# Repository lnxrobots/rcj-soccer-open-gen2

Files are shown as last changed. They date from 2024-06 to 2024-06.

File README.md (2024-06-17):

# RoboCup Soccer Open, Gen 2

## Setup

### Clone

Clone this repository in the home directory.

### Enable SSH and UART

Using `sudo raspi-config`

### Install packages and libraries

```
sudo apt install python3-pip git i2c-tools python3-opencv python3-serial python3-websockets
```

```
pip3 install bluedot
```

### Set cameras and optionally disable builtin Bluetooth

Add following lines to `/boot/firmware/config.txt`, change cameras if needed:

```
# Automatically load overlays for detected cameras
camera_auto_detect=0
dtoverlay=imx708,rotation=0,cam0
dtoverlay=imx477,cam1

# Uncomment to disable builtin bluetooth - custom
#dtoverlay=disable-bt
```

### Add launcher to autostart

Run `Launcher/apply_service.sh`.

### Pairing robots

Pair using [bluedot manual](https://bluedot.readthedocs.io/en/latest/pairpipi.html).

### Camera

Obtain frames using [Picamera2](https://github.com/raspberrypi/picamera2).

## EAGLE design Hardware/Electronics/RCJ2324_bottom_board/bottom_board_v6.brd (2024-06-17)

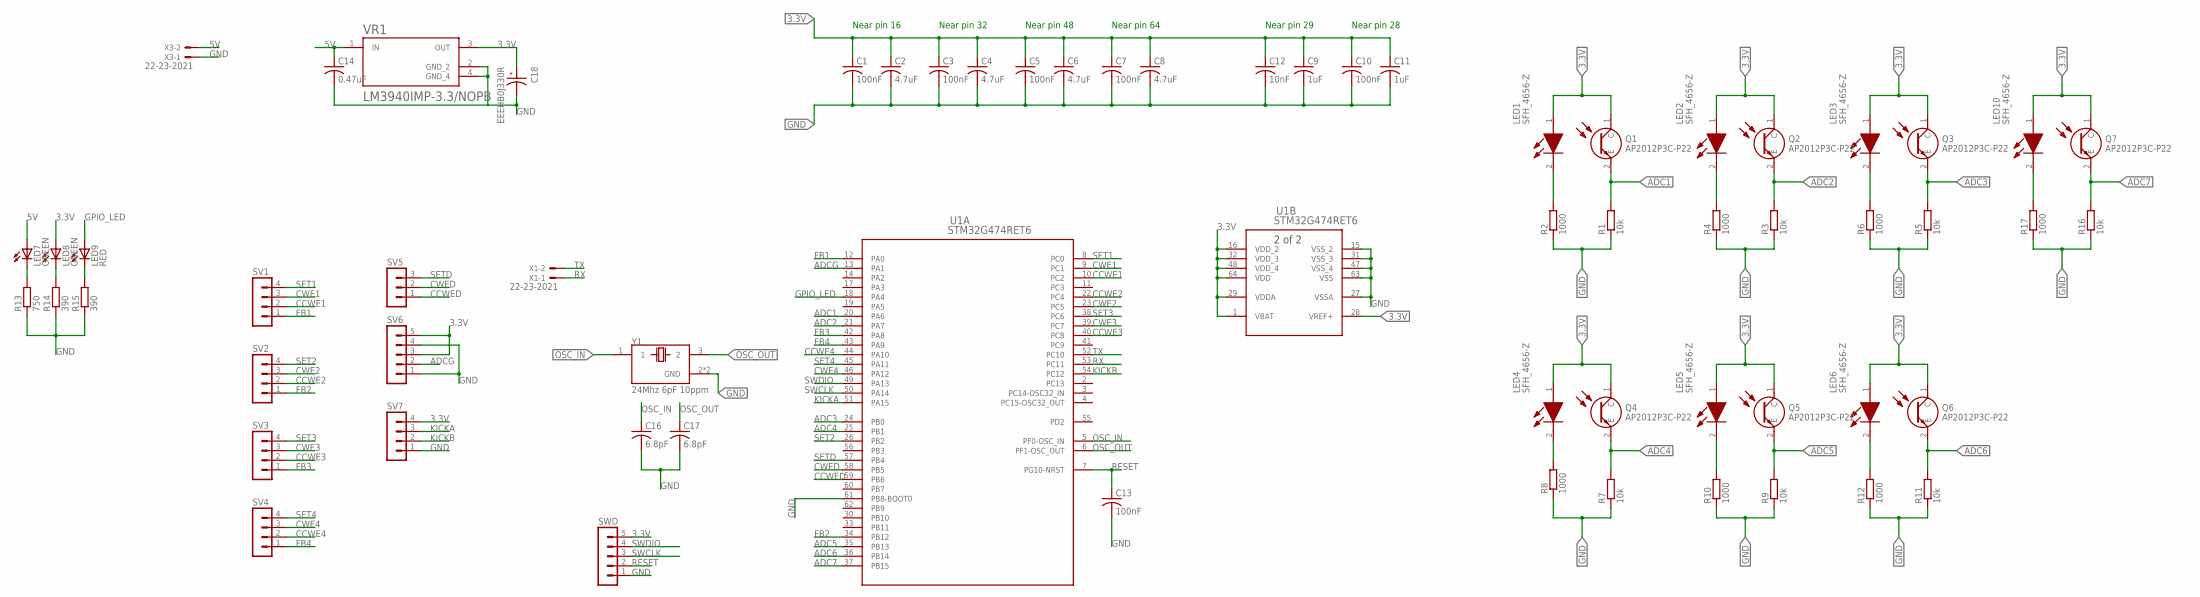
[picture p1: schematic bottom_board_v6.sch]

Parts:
C1, C3, C5, C7, C10, C13: 100nF; C0603
C2, C4, C6, C8: 4.7uF; C0603
C9, C11: 1uF; C0603
C12: 10nF; C0603
C14: 0.47uF; C0603
C16, C17: 6.8pF; C0603
C18: EEEHB0J330R; CAP_EEEHB0J330R
LED1, LED2, LED3, LED4, LED5, LED6, LED10: SFH_4656-Z; SFH4656Z
LED7, LED8: GREEN; CHIPLED_0603
LED9: RED; CHIPLED_0603
Q1, Q2, Q3, Q4, Q5, Q6, Q7: AP2012P3C-P22; AP2012P3CP22
R1, R3, R5, R7, R9, R11, R16: 10k; R0603
R2, R4, R6, R8, R10, R12, R17: 1000; R0603
R13: 750; R0603
R14, R15: 390; R0603
SV1, SV2, SV3, SV4, SV7: MA04-1
SV5: MA03-1
SV6: MA05-1
SWD: MA05-1
U1: STM32G474RET6; LQFP64-10X10MM
VR1: LM3940IMP-3.3/NOPB; VREG_LM3940IMP-3.3/NOPB
X1, X3: 22-23-2021
Y1: 24Mhz 6pF 10ppm; XTAL_TSX-3225_16.0000MF18X-AC3

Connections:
3.3V: C1.1, C2.1, C3.1, C4.1, C5.1, C6.1, C7.1, C8.1, C9.1, C10.1, C11.1, C12.1, C18.1, LED1.1 (A), LED2.1 (A), LED3.1 (A), LED4.1 (A), LED5.1 (A), LED6.1 (A), LED8.A, LED10.1 (A), Q1.1 (C), Q2.1 (C), Q3.1 (C), Q4.1 (C), Q5.1 (C), Q6.1 (C), Q7.1 (C), SV6.3, SV6.5, SV7.4, SWD.5, U1.1 (VBAT), U1.16 (VDD_2), U1.28 (VREF+), U1.29 (VDDA), U1.32 (VDD_3), U1.48 (VDD_4), U1.64 (VDD), VR1.3 (OUT)
5V: C14.1, LED7.A, VR1.1 (IN), X3.2
ADC1: Q1.2 (E), R1.2, U1.20 (PA6)
ADC2: Q2.2 (E), R3.2, U1.21 (PA7)
ADC3: Q3.2 (E), R5.2, U1.24 (PB0)
ADC4: Q4.2 (E), R7.2, U1.25 (PB1)
ADC5: Q5.2 (E), R9.2, U1.35 (PB13)
ADC6: Q6.2 (E), R11.2, U1.36 (PB14)
ADC7: Q7.2 (E), R16.2, U1.37 (PB15)
ADCG: SV6.2, U1.13 (PA1)
CCWE1: SV1.2, U1.10 (PC2)
CCWE2: SV2.2, U1.22 (PC4)
CCWE3: SV3.2, U1.40 (PC8)
CCWE4: SV4.2, U1.44 (PA10)
CCWED: SV5.1, U1.59 (PB6)
CWE1: SV1.3, U1.9 (PC1)
CWE2: SV2.3, U1.23 (PC5)
CWE3: SV3.3, U1.39 (PC7)
CWE4: SV4.3, U1.46 (PA12)
CWED: SV5.2, U1.58 (PB5)
FB1: SV1.1, U1.12 (PA0)
FB2: SV2.1, U1.34 (PB12)
FB3: SV3.1, U1.42 (PA8)
FB4: SV4.1, U1.43 (PA9)
GND: C1.2, C2.2, C3.2, C4.2, C5.2, C6.2, C7.2, C8.2, C9.2, C10.2, C11.2, C12.2, C13.2, C14.2, C16.2, C17.2, C18.2, R1.1, R2.1, R3.1, R4.1, R5.1, R6.1, R7.1, R8.1, R9.1, R10.1, R11.1, R12.1, R13.1, R14.1, R15.1, R16.1, R17.1, SV6.1, SV6.4, SV7.1, SWD.1, U1.15 (VSS_2), U1.27 (VSSA), U1.31 (VSS_3), U1.47 (VSS_4), U1.61 (PB8-BOOT0), U1.63 (VSS), VR1.2 (GND_2), VR1.4 (GND_4), X3.1, Y1.2 (GND), Y1.4 (GND)
GPIO_LED: LED9.A, U1.18 (PA4)
KICKA: SV7.3, U1.51 (PA15)
KICKB: SV7.2, U1.54 (PC12)
unnamed: LED2.2 (K), R4.2
unnamed: LED3.2 (K), R6.2
unnamed: LED1.2 (K), R2.2
unnamed: LED4.2 (K), R8.2
unnamed: LED5.2 (K), R10.2
unnamed: LED6.2 (K), R12.2
unnamed: LED7.C, R13.2
unnamed: LED8.C, R14.2
unnamed: LED9.C, R15.2
unnamed: LED10.2 (K), R17.2
OSC_IN: C16.1, U1.5 (PF0-OSC_IN), Y1.1
OSC_OUT: C17.1, U1.6 (PF1-OSC_OUT), Y1.3 (2)
RESET: C13.1, SWD.2, U1.7 (PG10-NRST)
RX: U1.53 (PC11), X1.1
SET1: SV1.4, U1.8 (PC0)
SET2: SV2.4, U1.26 (PB2)
SET3: SV3.4, U1.38 (PC6)
SET4: SV4.4, U1.45 (PA11)
SETD: SV5.3, U1.57 (PB4)
SWCLK: SWD.3, U1.50 (PA14)
SWDIO: SWD.4, U1.49 (PA13)
TX: U1.52 (PC10), X1.2

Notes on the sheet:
Near pin 16
Near pin 32
Near pin 48
Near pin 64
Near pin 29
Near pin 28

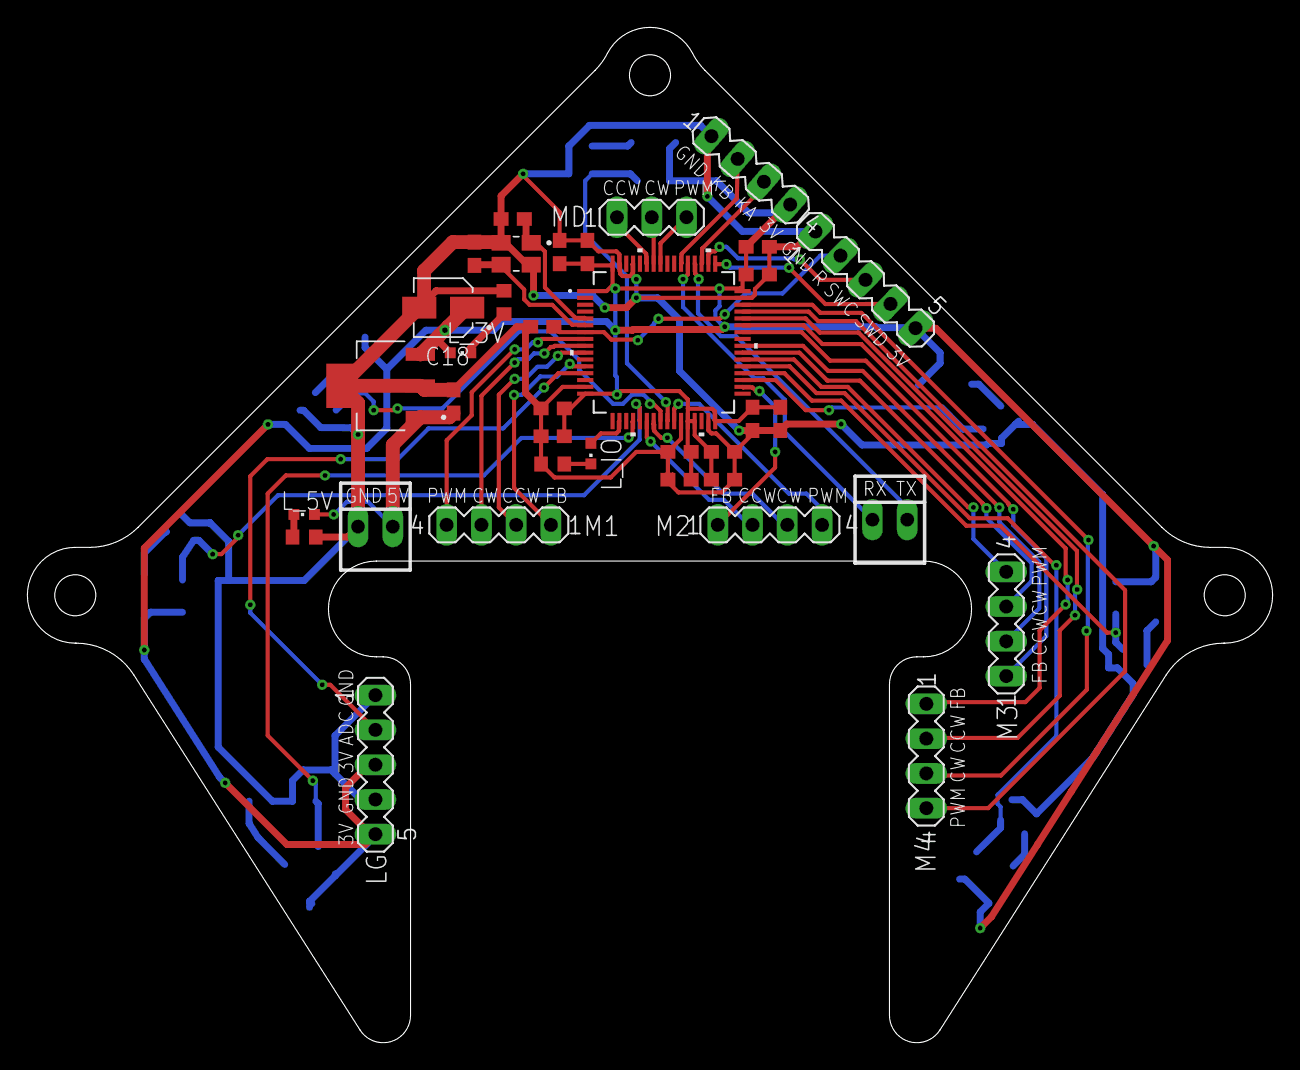
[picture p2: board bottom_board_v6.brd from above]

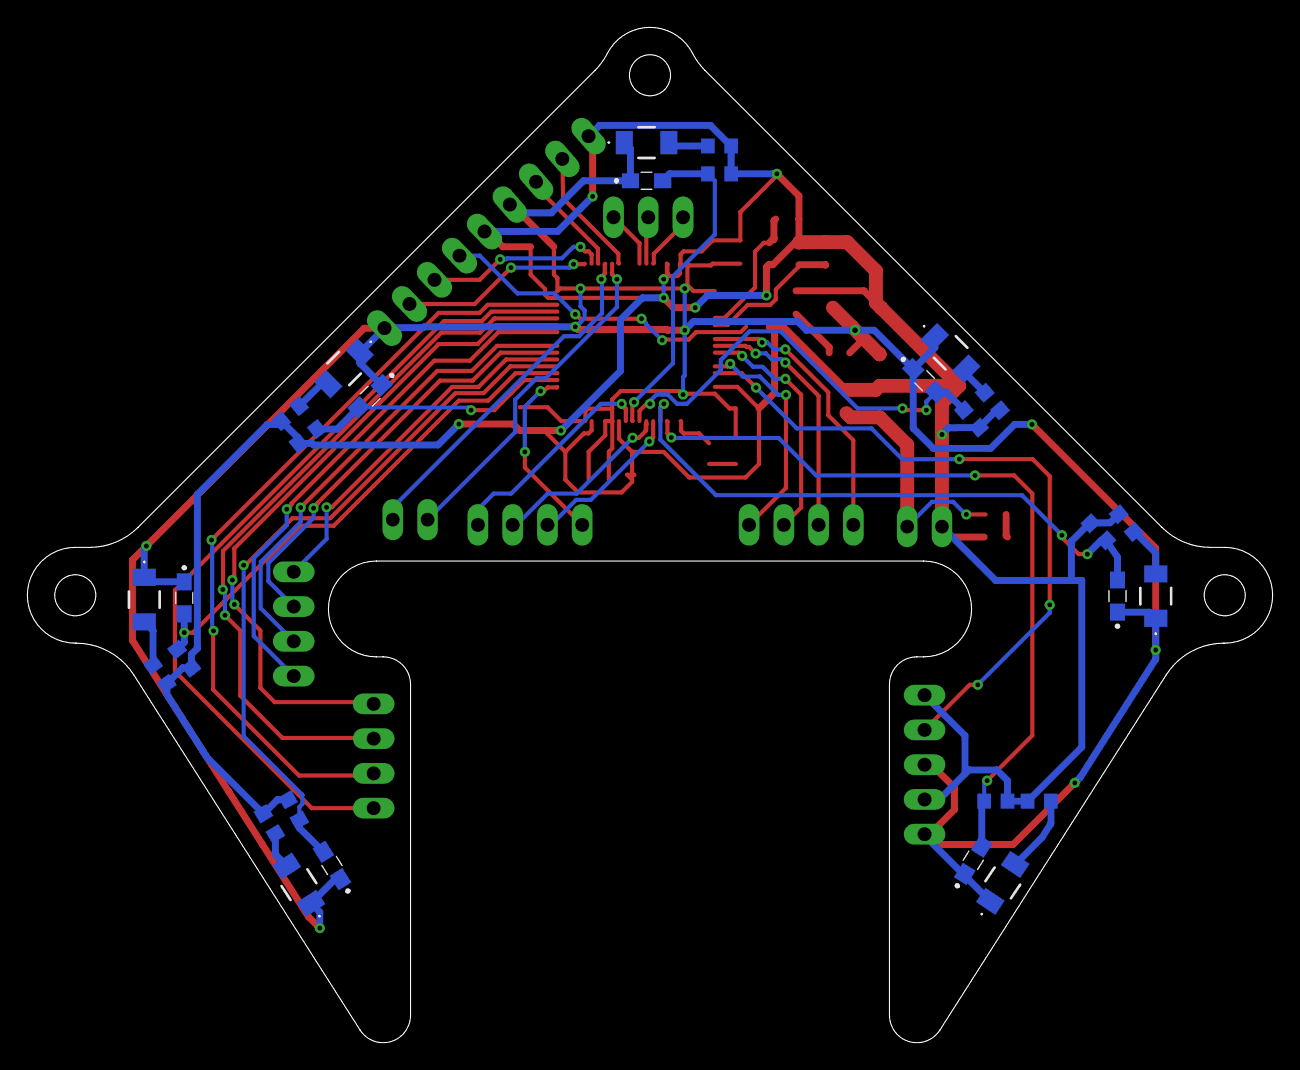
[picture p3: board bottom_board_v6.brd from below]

Board: 2 copper layers, 91.0 x 74.2 mm, 64 parts (28 on the bottom side), 50 nets.

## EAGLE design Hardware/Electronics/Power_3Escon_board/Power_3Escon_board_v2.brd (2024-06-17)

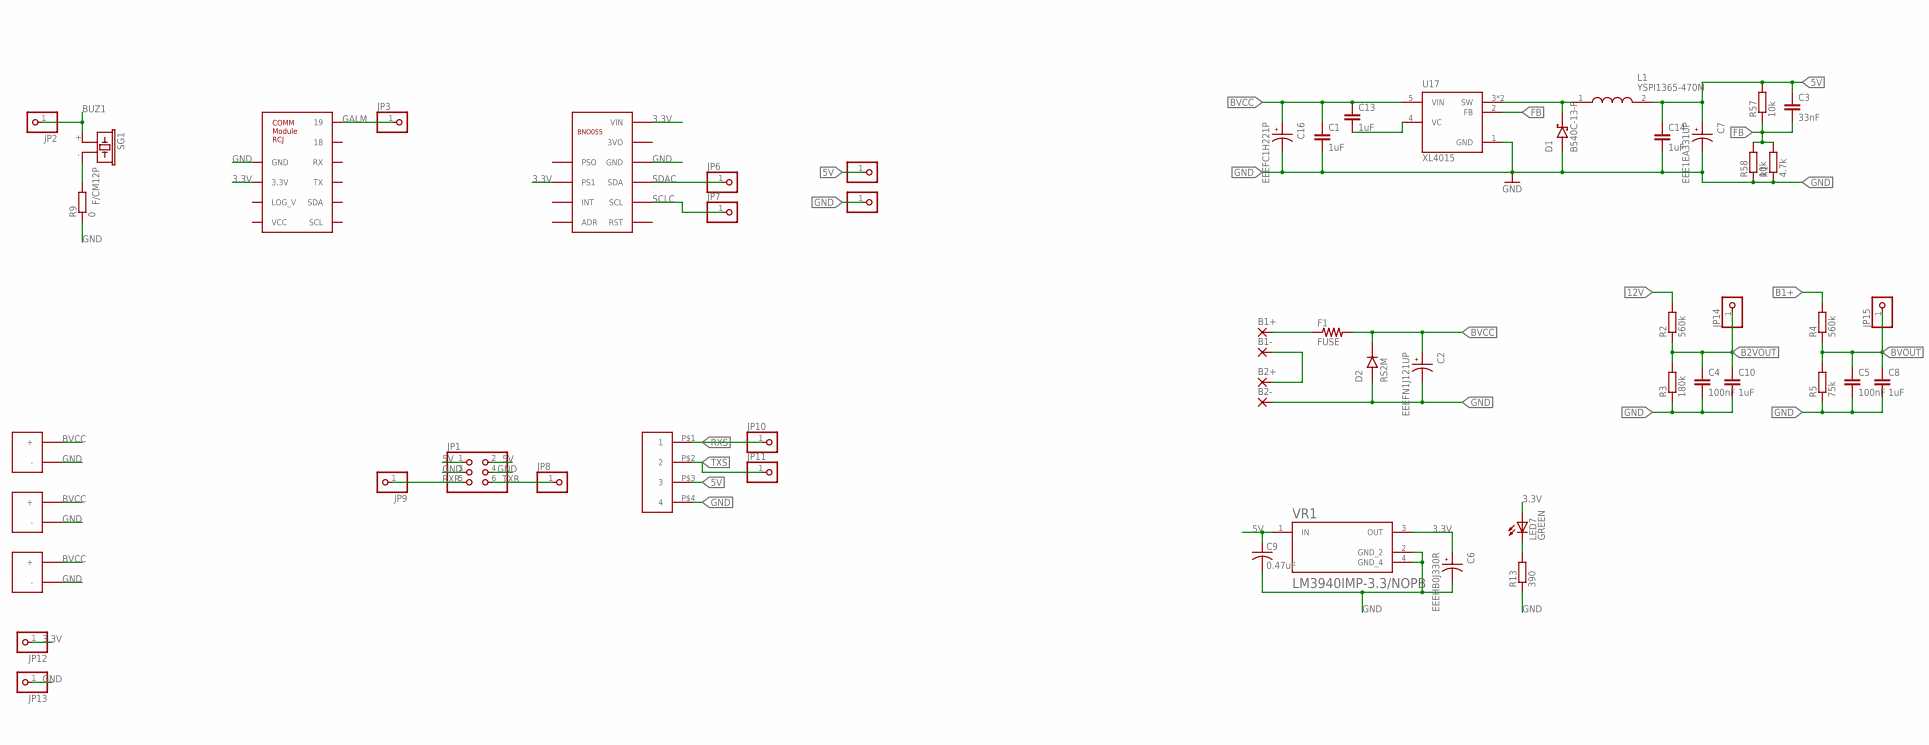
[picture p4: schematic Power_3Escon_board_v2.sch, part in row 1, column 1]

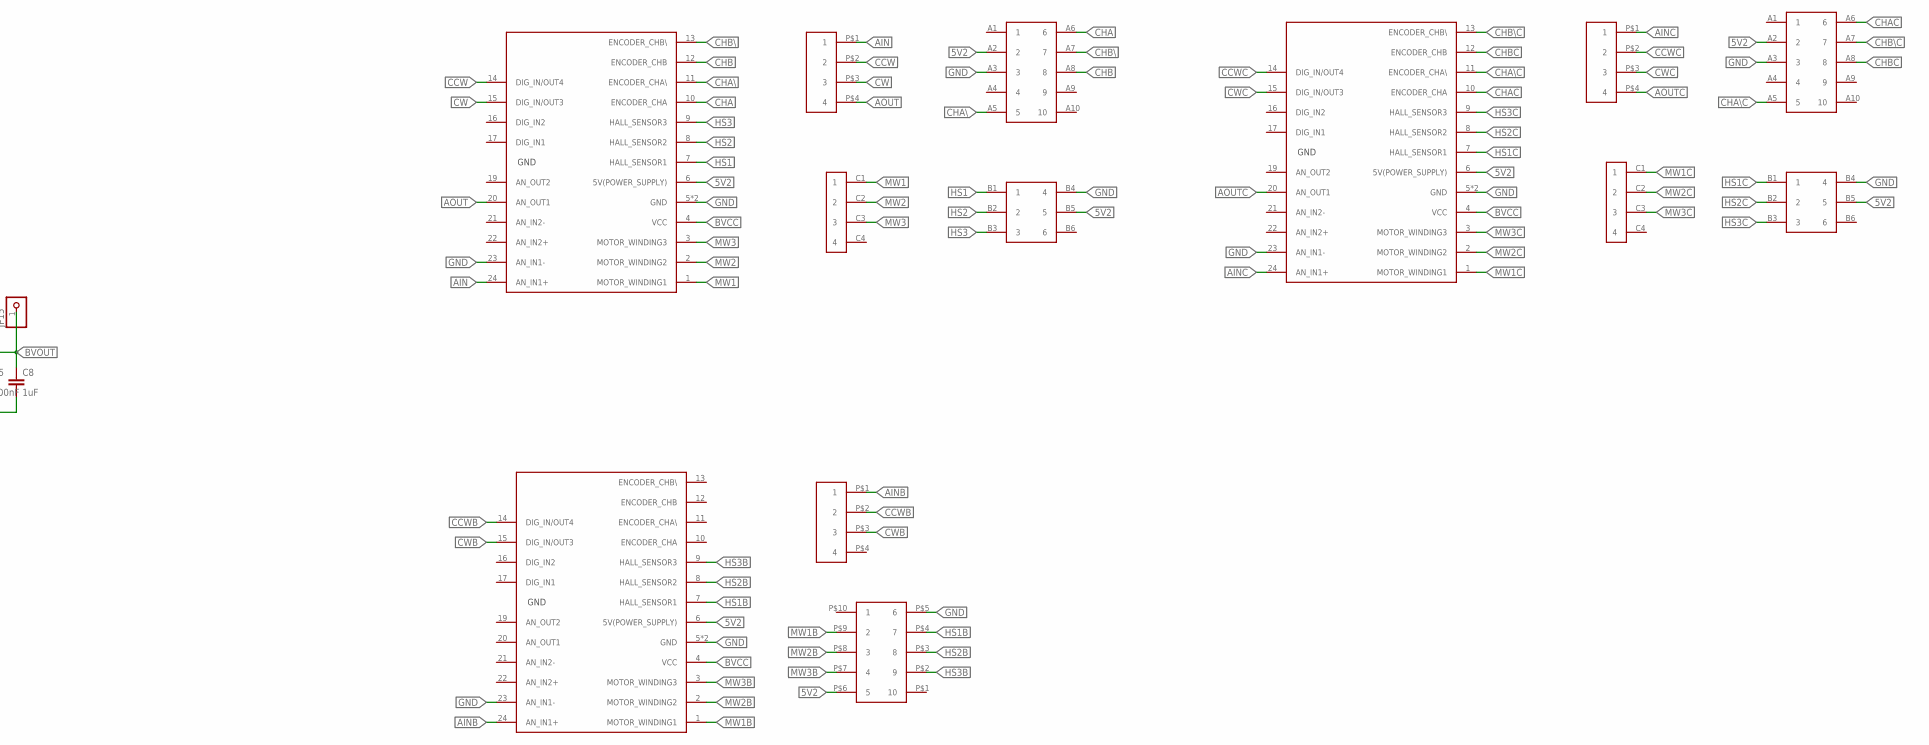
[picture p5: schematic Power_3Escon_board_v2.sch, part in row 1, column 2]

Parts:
B1+, B1-, B2+, B2-: 3,81/1,4
C1, C8, C10, C13, C14: 1uF; C0603
C2: EEEFN1J121UP; CAP_EEEFN1J121UP
C3: 33nF; C0603
C4, C5: 100nF; C0603
C6: EEEHB0J330R; CAP_EEEHB0J330R
C7: EEE1EA331UP; CAP_EEE1EA331UP
C9: 0.47uF; C0603
C16: EEEFC1H221P; CAP_EEEFC1H221P
D1: B540C-13-F; DIOM6959X245N
D2: RS2M; DIOM4336X265N
F1: FUSE; R1206
JP1: PINHD-2X3; 2X03
JP2, JP3, JP4, JP5, JP6, JP7, JP8, JP9, JP10, JP11, JP12, JP13, JP14, JP15: PINHD-1X1; 1X01
L1: YSPI1365-470M; INDPM138126X650N
LED7: GREEN; CHIPLED_0603
R1: 4.7k; R0603
R2, R4: 560k; R0603
R3: 180k; R0603
R5: 75k; R0603
R9: 0; R0603
R13: 390; R0603
R57, R58: 10k; R0603
SG1: F/CM12P
U17: XL4015; CONV_XL4015
U$1, U$10, U$15: ESCON24/224/2; ESCON24/2
U$2: GAL_MODULE
U$3: BNO055
U$4, U$13, U$16, U$22: 280378-2CONNECTOR
U$5, U$17: PIN2.54-2X5
U$6, U$18: MX-44914-0601
U$7, U$19: MX5566
U$14: 2,5MSF10
U$23, U$24, U$25: SVORKOVNICA3.5_P2; SVORKOVNICA3.5
VR1: LM3940IMP-3.3/NOPB; VREG_LM3940IMP-3.3/NOPB

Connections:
3.3V: C6.1, JP12.1, LED7.A, U$2.3.3V, U$3.PS1, U$3.VIN, VR1.3 (OUT)
5V: C3.1, C7.1, C9.1, C14.1, JP1.1, JP1.2, JP4.1, L1.2, R57.2, U$22.P$3 (3), VR1.1 (IN)
5V2: U$1.6 (5V(POWER_SUPPLY)), U$5.A2 (2), U$6.B5 (5), U$10.6 (5V(POWER_SUPPLY)), U$14.P$6 (5), U$15.6 (5V(POWER_SUPPLY)), U$17.A2 (2), U$18.B5 (5)
12V: B1-.1, B2+.1, R2.2
AIN: U$1.24 (AN_IN1+), U$4.P$1 (1)
AINB: U$10.24 (AN_IN1+), U$13.P$1 (1)
AINC: U$15.24 (AN_IN1+), U$16.P$1 (1)
AOUT: U$1.20 (AN_OUT1), U$4.P$4 (4)
AOUTC: U$15.20 (AN_OUT1), U$16.P$4 (4)
B1+: B1+.1, F1.1, R4.2
B2VOUT: C4.1, C10.1, JP14.1, R2.1, R3.2
BUZ1: JP2.1, SG1.+ (1)
BVCC: C1.1, C2.1, C13.1, C16.1, D2.C (K), F1.2, U17.5 (VIN), U$1.4 (VCC), U$10.4 (VCC), U$15.4 (VCC), U$23.P$1 (+), U$24.P$1 (+), U$25.P$1 (+)
BVOUT: C5.1, C8.1, JP15.1, R4.1, R5.2
CCW: U$1.14 (DIG_IN/OUT4), U$4.P$2 (2)
CCWB: U$10.14 (DIG_IN/OUT4), U$13.P$2 (2)
CCWC: U$15.14 (DIG_IN/OUT4), U$16.P$2 (2)
CHA: U$1.10 (ENCODER_CHA), U$5.A6 (6)
CHAC: U$15.10 (ENCODER_CHA), U$17.A6 (6)
CHA\\: U$1.11 (ENCODER_CHA\\), U$5.A5 (5)
CHA\\C: U$15.11 (ENCODER_CHA\\), U$17.A5 (5)
CHB: U$1.12 (ENCODER_CHB), U$5.A8 (8)
CHBC: U$15.12 (ENCODER_CHB), U$17.A8 (8)
CHB\\: U$1.13 (ENCODER_CHB\\), U$5.A7 (7)
CHB\\C: U$15.13 (ENCODER_CHB\\), U$17.A7 (7)
CW: U$1.15 (DIG_IN/OUT3), U$4.P$3 (3)
CWB: U$10.15 (DIG_IN/OUT3), U$13.P$3 (3)
CWC: U$15.15 (DIG_IN/OUT3), U$16.P$3 (3)
FB: C3.2, R1.2, R57.1, R58.2, U17.2 (FB)
GALM: JP3.1, U$2.19
GND: B2-.1, C1.2, C2.2, C4.2, C5.2, C6.2, C7.2, C8.2, C9.2, C10.2, C14.2, C16.2, D1.A, D2.A, JP1.3, JP1.4, JP5.1, JP13.1, R1.1, R3.1, R5.1, R9.1, R13.1, R58.1, U17.1 (GND), U$1.5 (GND), U$1.18 (GND), U$1.23 (AN_IN1-), U$2.GND, U$3.GND, U$5.A3 (3), U$6.B4 (4), U$10.5 (GND), U$10.18 (GND), U$10.23 (AN_IN1-), U$14.P$5 (6), U$15.5 (GND), U$15.18 (GND), U$15.23 (AN_IN1-), U$17.A3 (3), U$18.B4 (4), U$22.P$4 (4), U$23.P$2 (-), U$24.P$2 (-), U$25.P$2 (-), VR1.2 (GND_2), VR1.4 (GND_4)
HS1: U$1.7 (HALL_SENSOR1), U$6.B1 (1)
HS1B: U$10.7 (HALL_SENSOR1), U$14.P$4 (7)
HS1C: U$15.7 (HALL_SENSOR1), U$18.B1 (1)
HS2: U$1.8 (HALL_SENSOR2), U$6.B2 (2)
HS2B: U$10.8 (HALL_SENSOR2), U$14.P$3 (8)
HS2C: U$15.8 (HALL_SENSOR2), U$18.B2 (2)
HS3: U$1.9 (HALL_SENSOR3), U$6.B3 (3)
HS3B: U$10.9 (HALL_SENSOR3), U$14.P$2 (9)
HS3C: U$15.9 (HALL_SENSOR3), U$18.B3 (3)
MW1: U$1.1 (MOTOR_WINDING1), U$7.C1 (1)
MW1B: U$10.1 (MOTOR_WINDING1), U$14.P$9 (2)
MW1C: U$15.1 (MOTOR_WINDING1), U$19.C1 (1)
MW2: U$1.2 (MOTOR_WINDING2), U$7.C2 (2)
MW2B: U$10.2 (MOTOR_WINDING2), U$14.P$8 (3)
MW2C: U$15.2 (MOTOR_WINDING2), U$19.C2 (2)
MW3: U$1.3 (MOTOR_WINDING3), U$7.C3 (3)
MW3B: U$10.3 (MOTOR_WINDING3), U$14.P$7 (4)
MW3C: U$15.3 (MOTOR_WINDING3), U$19.C3 (3)
unnamed: LED7.C, R13.2
unnamed: C13.2, U17.4 (VC)
unnamed: R9.2, SG1.- (2)
unnamed: D1.C (K), L1.1, U17.3 (SW), U17.3.1 (SW)
RXR: JP1.5, JP9.1
RXS: JP10.1, U$22.P$1 (1)
SCLC: JP7.1, U$3.SCL
SDAC: JP6.1, U$3.SDA
TXR: JP1.6, JP8.1
TXS: JP11.1, U$22.P$2 (2)

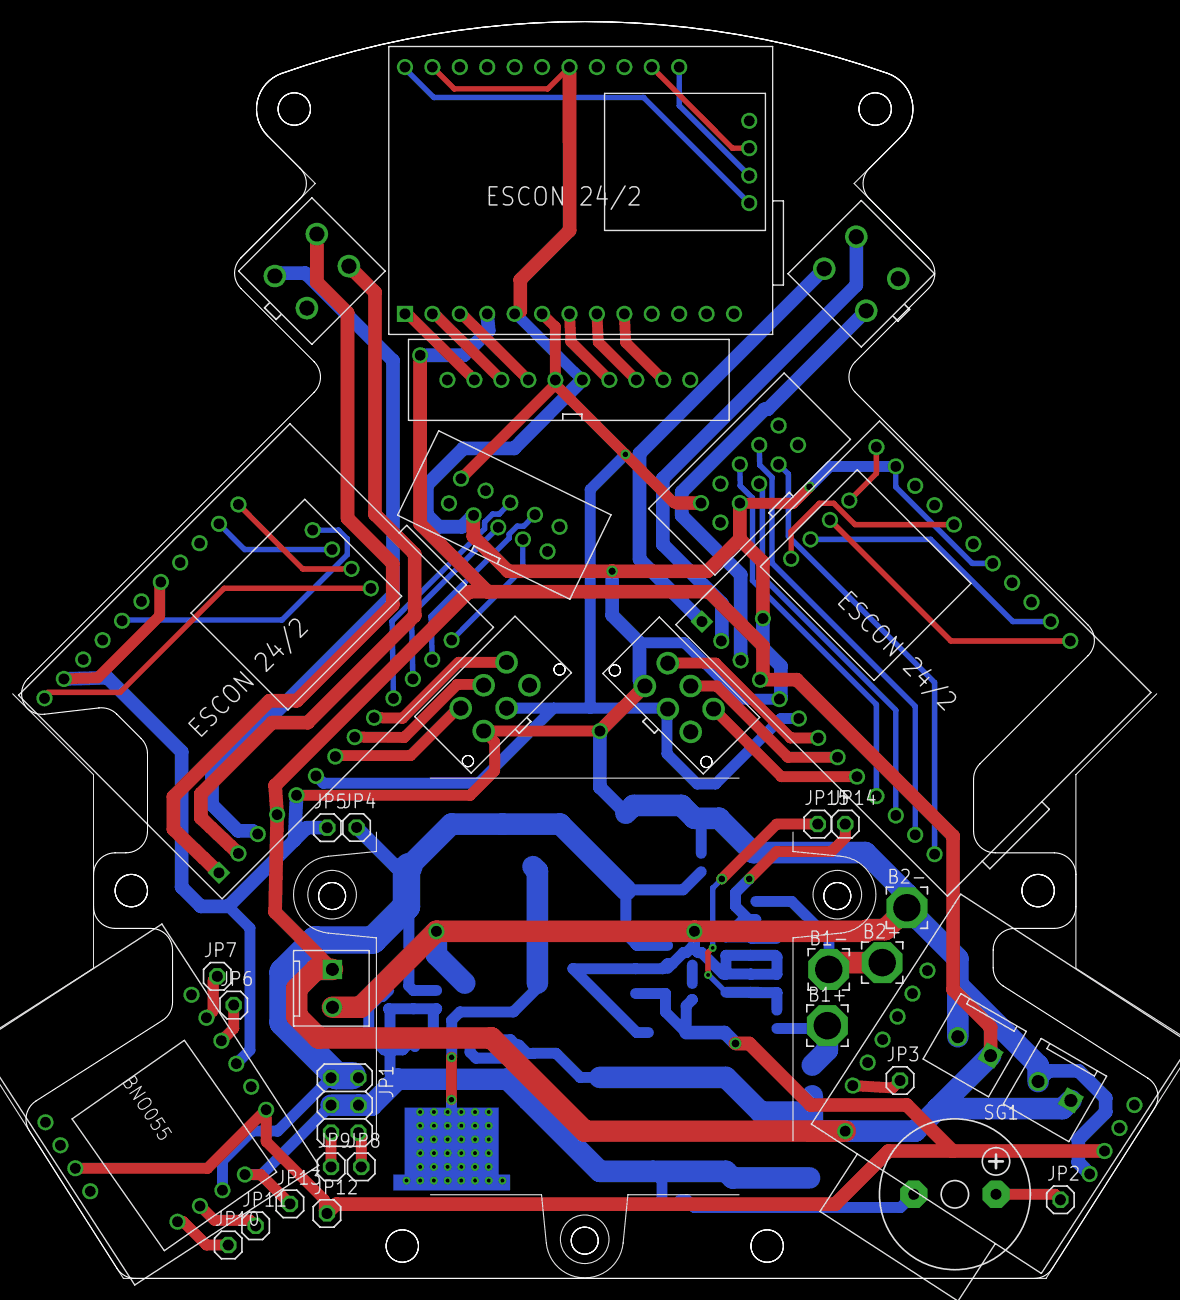
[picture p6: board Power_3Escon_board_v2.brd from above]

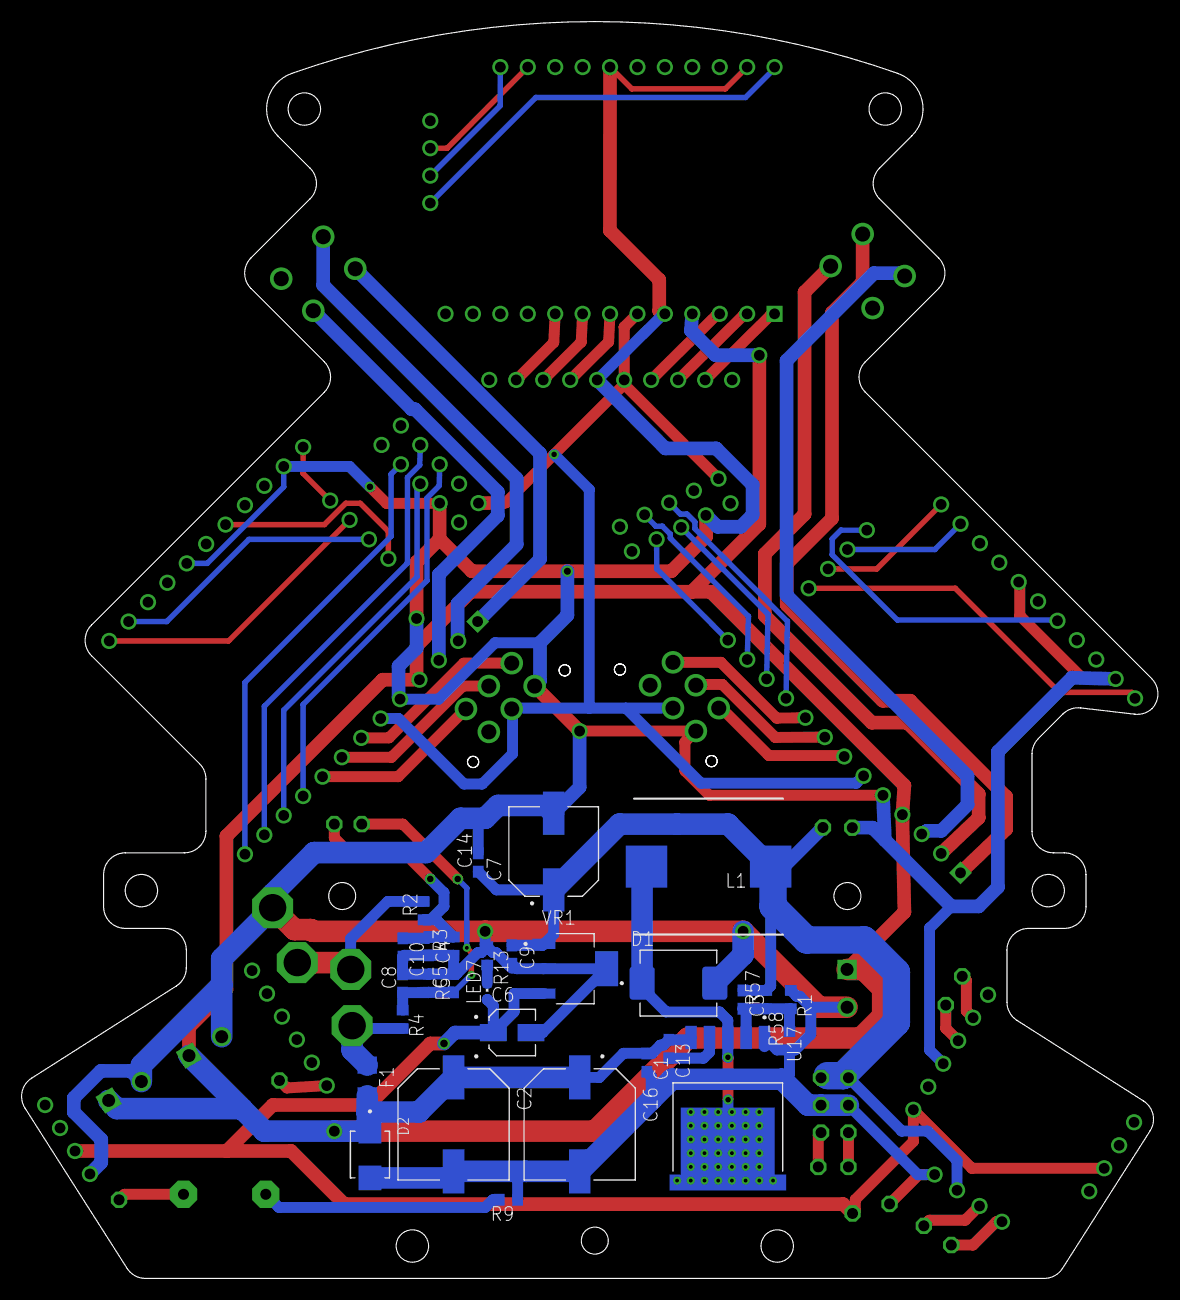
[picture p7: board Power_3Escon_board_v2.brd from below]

Board: 2 copper layers, 105.3 x 116.4 mm, 68 parts (29 on the bottom side), 59 nets.

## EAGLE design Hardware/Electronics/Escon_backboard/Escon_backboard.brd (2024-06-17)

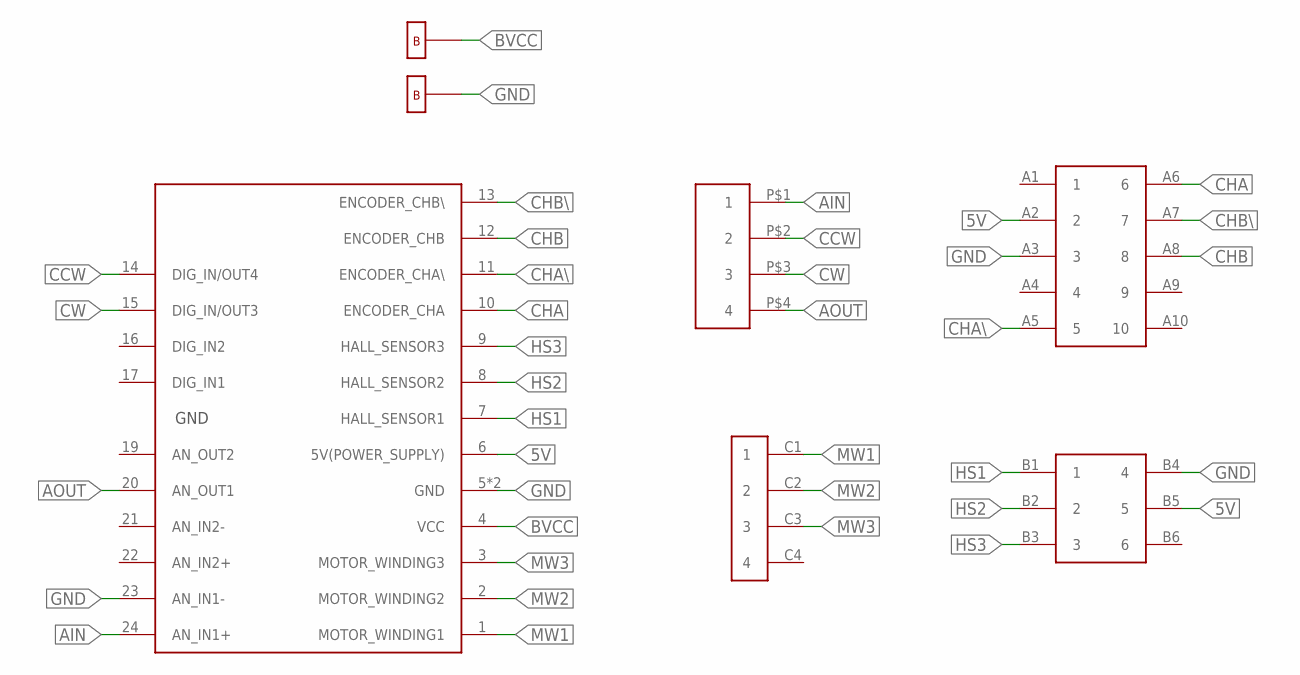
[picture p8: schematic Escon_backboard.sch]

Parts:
U$1: ESCON24/224/2; ESCON24/2
U$2: 280378-2CONNECTOR
U$3: PIN2.54-2X5
U$4: MX-44914-0601
U$5: MX5566
U$6, U$7: BHOLE

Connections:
5V: U$1.6 (5V(POWER_SUPPLY)), U$3.A2 (2), U$4.B5 (5)
AIN: U$1.24 (AN_IN1+), U$2.P$1 (1)
AOUT: U$1.20 (AN_OUT1), U$2.P$4 (4)
BVCC: U$1.4 (VCC), U$6.P$1
CCW: U$1.14 (DIG_IN/OUT4), U$2.P$2 (2)
CHA: U$1.10 (ENCODER_CHA), U$3.A6 (6)
CHA\\: U$1.11 (ENCODER_CHA\\), U$3.A5 (5)
CHB: U$1.12 (ENCODER_CHB), U$3.A8 (8)
CHB\\: U$1.13 (ENCODER_CHB\\), U$3.A7 (7)
CW: U$1.15 (DIG_IN/OUT3), U$2.P$3 (3)
GND: U$1.5 (GND), U$1.18 (GND), U$1.23 (AN_IN1-), U$3.A3 (3), U$4.B4 (4), U$7.P$1
HS1: U$1.7 (HALL_SENSOR1), U$4.B1 (1)
HS2: U$1.8 (HALL_SENSOR2), U$4.B2 (2)
HS3: U$1.9 (HALL_SENSOR3), U$4.B3 (3)
MW1: U$1.1 (MOTOR_WINDING1), U$5.C1 (1)
MW2: U$1.2 (MOTOR_WINDING2), U$5.C2 (2)
MW3: U$1.3 (MOTOR_WINDING3), U$5.C3 (3)

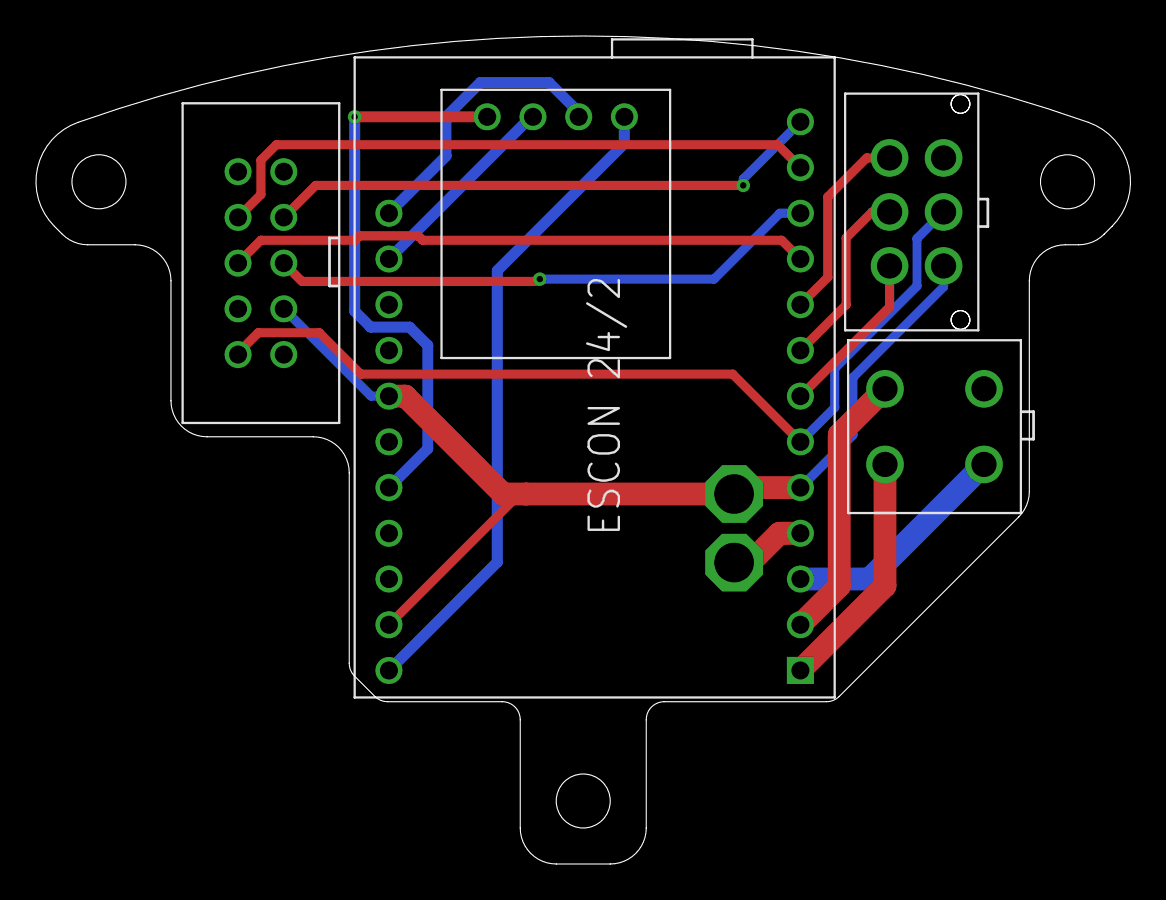
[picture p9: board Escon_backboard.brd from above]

Board: 2 copper layers, 60.8 x 46.0 mm, 7 parts (0 on the bottom side), 17 nets.

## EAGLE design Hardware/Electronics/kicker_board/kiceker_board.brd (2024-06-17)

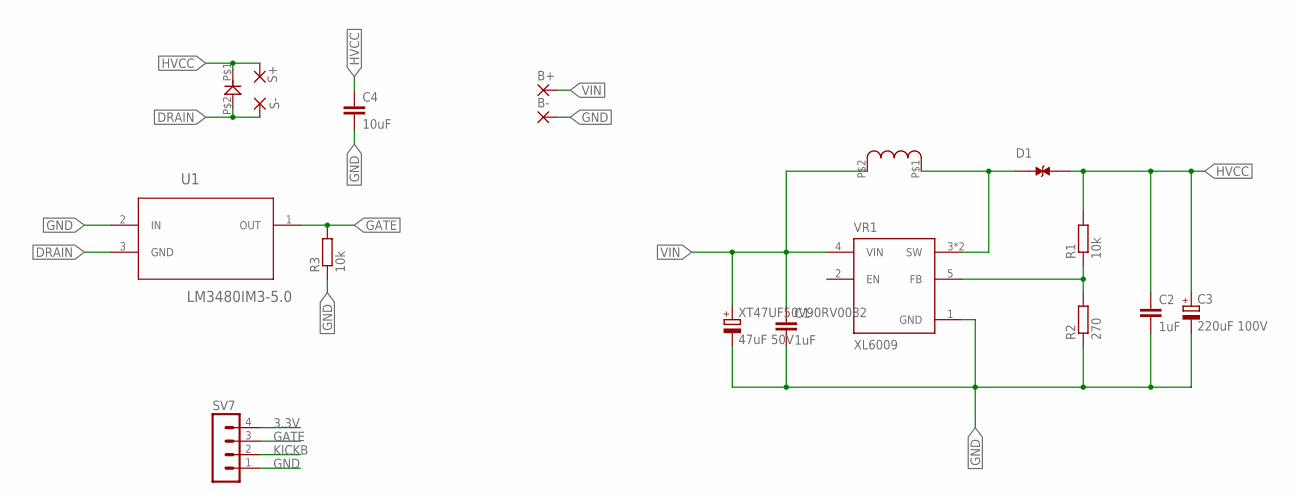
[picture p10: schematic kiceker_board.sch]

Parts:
B+: 3,81/1,4
B-: 3,81/1,4
C1, C2: 1uF; C0603
C3: 220uF 100V; E5-5
C4: 10uF; C0603
D1: SMCJ15CA_V7G; DIOM6859X262N
R1, R3: 10k; R0603
R2: 270; R0603
S+: 3,81/1,4
S-: 3,81/1,4
SV7: MA04-1
U1: LM3480IM3-5.0; SOT95P263X110-3N
U$1: TMPC1265
U$2: SMBF
VR1: XL6009; DPAK170P1435X465-6N
XT47UF50V90RV0082: 47uF 50V; 153CLV-0605

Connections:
3.3V: SV7.4
DRAIN: S-.1, U1.3 (GND), U$2.P$2
GATE: R3.2, SV7.3, U1.1 (OUT)
GND: B-.1, C1.2, C2.2, C3.-, C4.2, R2.1, R3.1, SV7.1, U1.2 (IN), VR1.1 (GND), XT47UF50V90RV0082.-
HVCC: C2.1, C3.+, C4.1, D1.2, R1.2, S+.1, U$2.P$1
KICKB: SV7.2
unnamed: D1.1, U$1.P$1, VR1.3 (SW), VR1.6 (SW)
unnamed: R1.1, R2.2, VR1.5 (FB)
VIN: B+.1, C1.1, U$1.P$2, VR1.4 (VIN), XT47UF50V90RV0082.+

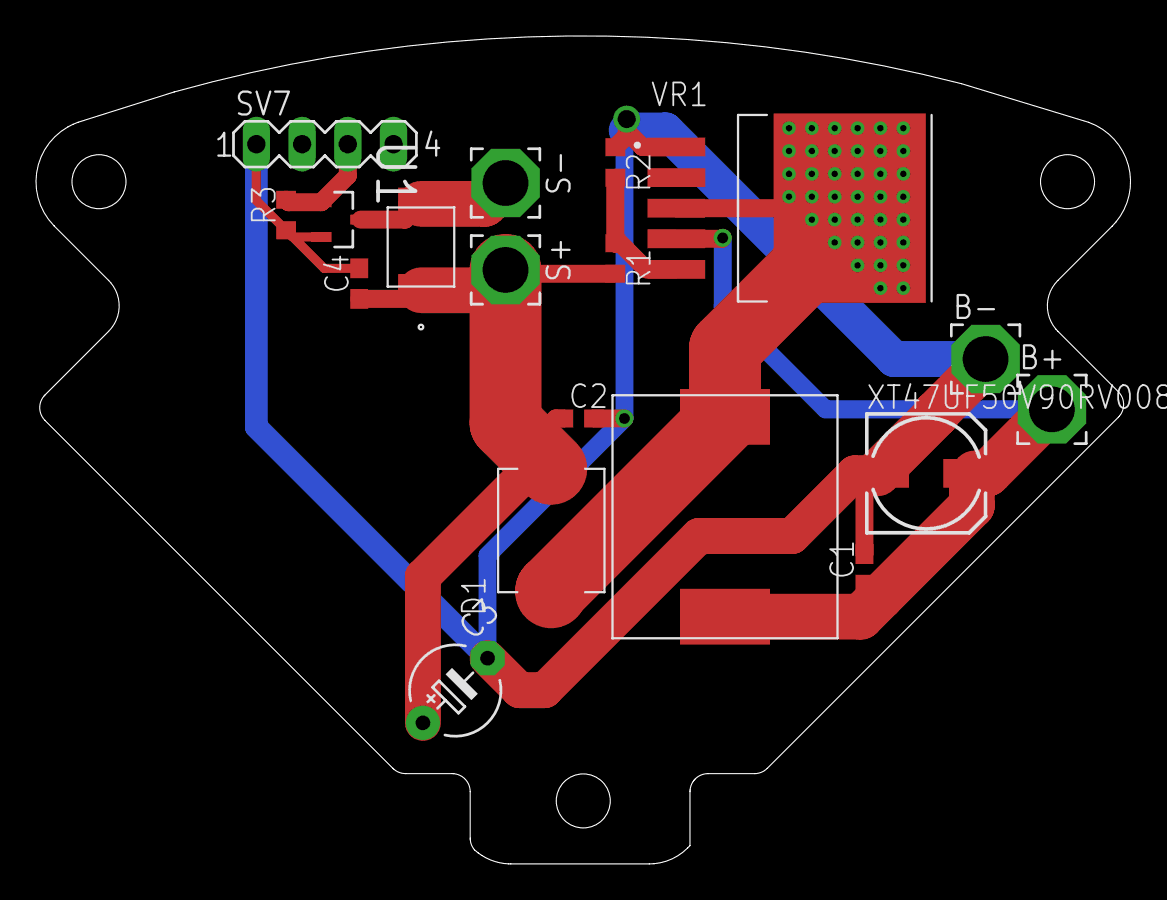
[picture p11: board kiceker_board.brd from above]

Board: 2 copper layers, 60.8 x 46.0 mm, 18 parts (0 on the bottom side), 7 nets.

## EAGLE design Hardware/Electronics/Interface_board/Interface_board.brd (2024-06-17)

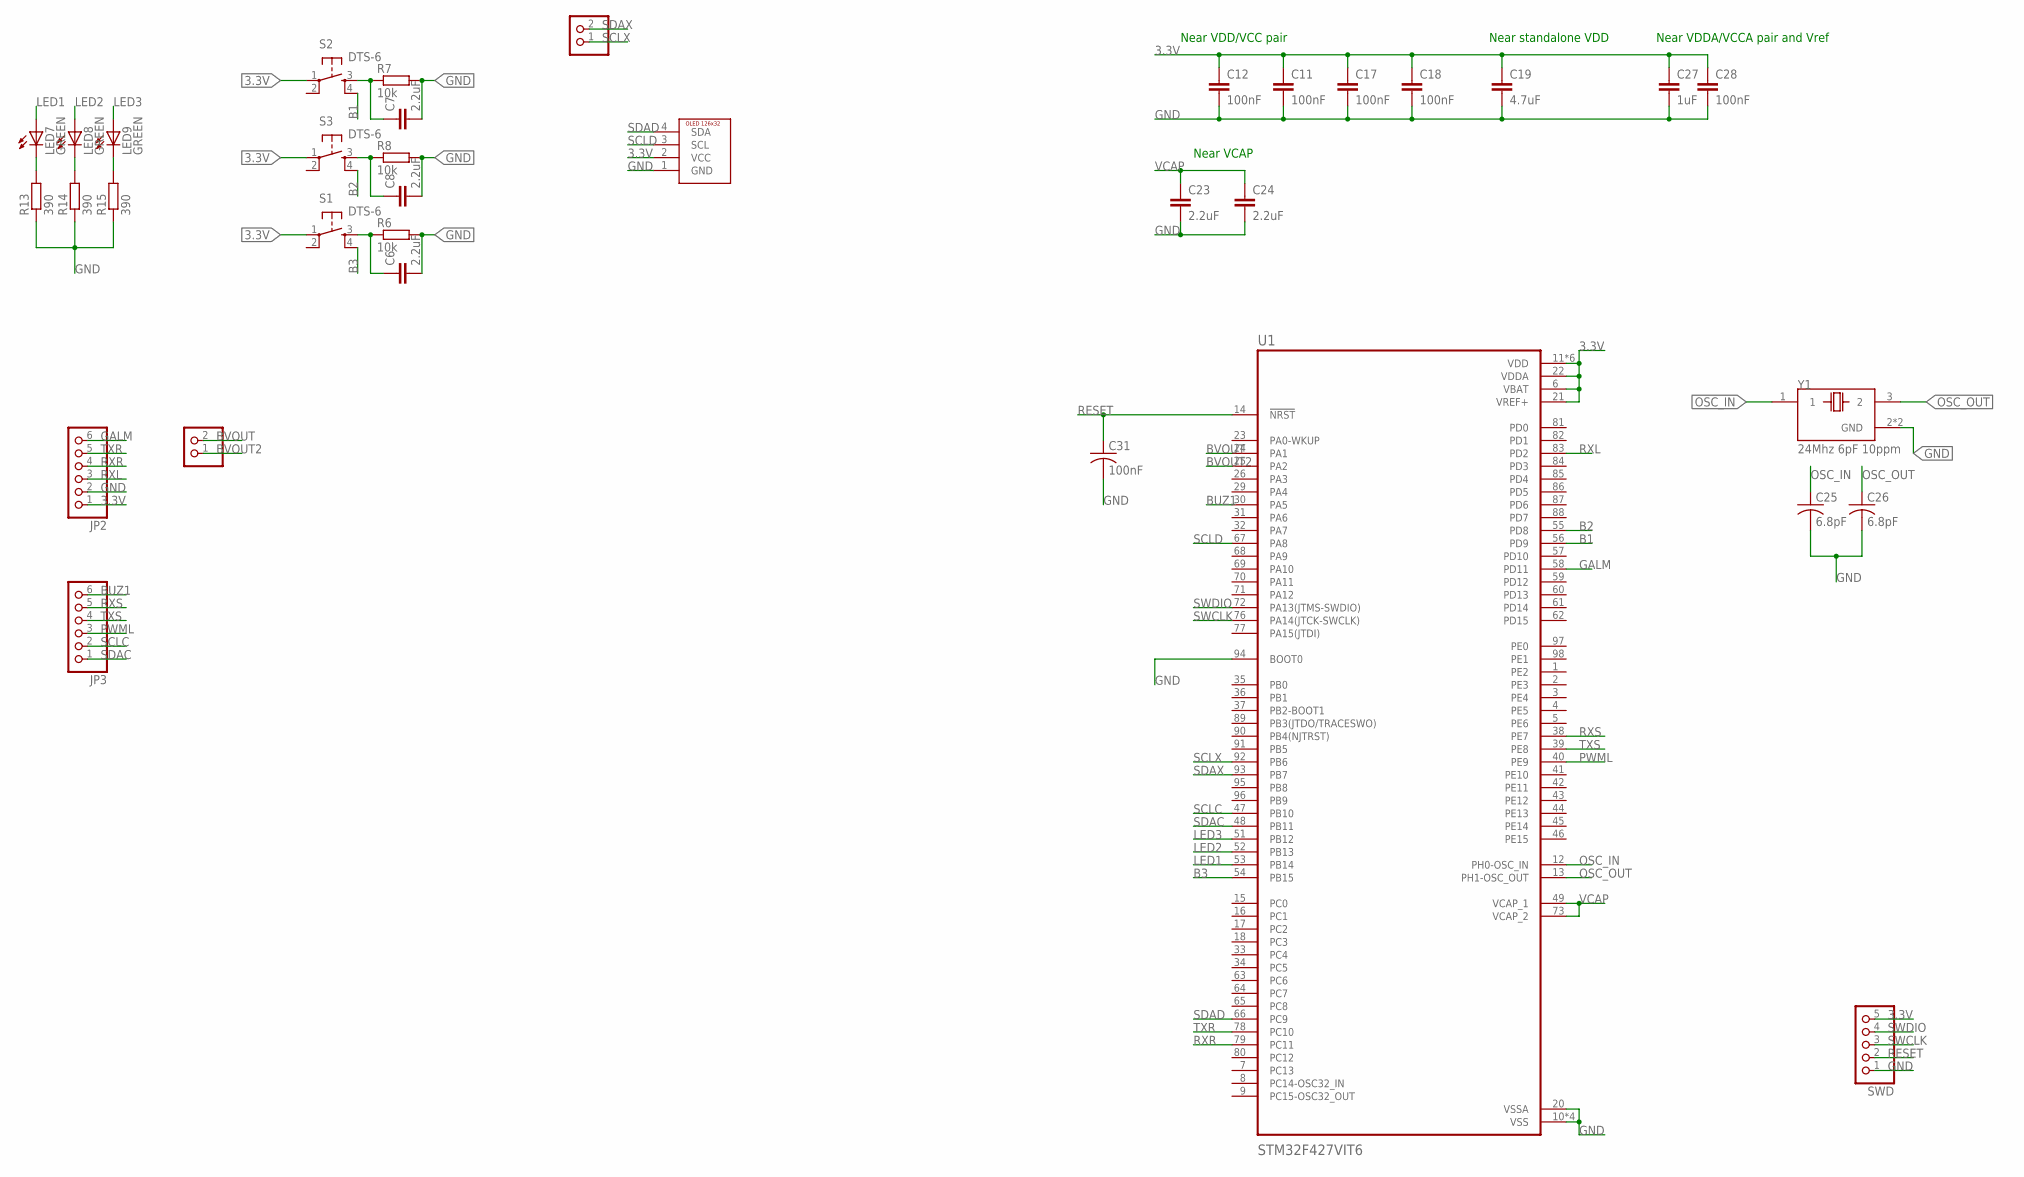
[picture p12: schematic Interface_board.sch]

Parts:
C6, C7, C8, C23, C24: 2.2uF; C0603
C11, C12, C17, C18, C28, C31: 100nF; C0603
C19: 4.7uF; C0603
C25, C26: 6.8pF; C0603
C27: 1uF; C0603
JP1, JP4: PINHD-1X2; 1X02
JP2, JP3: PINHD-1X6; 1X06
LED7, LED8, LED9: GREEN; CHIPLED_0603
R6, R7, R8: 10k; R0603
R13, R14, R15: 390; R0603
S1, S2, S3: DTS-6
SWD: PINHD-1X5/90; 1X05/90
U1: STM32F427VIT6; QFP50P1600X1600X160-100N
U$1: OLED126X32THROUGH_HOLE; OLED128X64
Y1: 24Mhz 6pF 10ppm; XTAL_TSX-3225_16.0000MF18X-AC3

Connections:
3.3V: C11.1, C12.1, C17.1, C18.1, C19.1, C27.1, C28.1, JP2.1, S1.1, S2.1, S3.1, SWD.5, U1.6 (VBAT), U1.11 (VDD), U1.19 (VDD), U1.21 (VREF+), U1.22 (VDDA), U1.28 (VDD), U1.50 (VDD), U1.75 (VDD), U1.100 (VDD), U$1.2 (VCC)
B1: S2.4, U1.56 (PD9)
B2: S3.4, U1.55 (PD8)
B3: S1.4, U1.54 (PB15)
BUZ1: JP3.6, U1.30 (PA5)
BVOUT: JP4.2, U1.24 (PA1)
BVOUT2: JP4.1, U1.25 (PA2)
GALM: JP2.6, U1.58 (PD11)
GND: C6.2, C7.2, C8.2, C11.2, C12.2, C17.2, C18.2, C19.2, C23.2, C24.2, C25.2, C26.2, C27.2, C28.2, C31.2, JP2.2, R6.2, R7.2, R8.2, R13.1, R14.1, R15.1, SWD.1, U1.10 (VSS), U1.20 (VSSA), U1.27 (VSS), U1.74 (VSS), U1.94 (BOOT0), U1.99 (VSS), U$1.1 (GND), Y1.2 (GND), Y1.4 (GND)
LED1: LED7.A, U1.53 (PB14)
LED2: LED8.A, U1.52 (PB13)
LED3: LED9.A, U1.51 (PB12)
unnamed: C6.1, R6.1, S1.3
unnamed: C7.1, R7.1, S2.3
unnamed: C8.1, R8.1, S3.3
unnamed: LED7.C, R13.2
unnamed: LED8.C, R14.2
unnamed: LED9.C, R15.2
OSC_IN: C25.1, U1.12 (PH0-OSC_IN), Y1.1
OSC_OUT: C26.1, U1.13 (PH1-OSC_OUT), Y1.3 (2)
PWML: JP3.3, U1.40 (PE9)
RESET: C31.1, SWD.2, U1.14 (!NRST)
RXL: JP2.3, U1.83 (PD2)
RXR: JP2.4, U1.79 (PC11)
RXS: JP3.5, U1.38 (PE7)
SCLC: JP3.2, U1.47 (PB10)
SCLD: U1.67 (PA8), U$1.3 (SCL)
SCLX: JP1.1, U1.92 (PB6)
SDAC: JP3.1, U1.48 (PB11)
SDAD: U1.66 (PC9), U$1.4 (SDA)
SDAX: JP1.2, U1.93 (PB7)
SWCLK: SWD.3, U1.76 (PA14(JTCK-SWCLK))
SWDIO: SWD.4, U1.72 (PA13(JTMS-SWDIO))
TXR: JP2.5, U1.78 (PC10)
TXS: JP3.4, U1.39 (PE8)
VCAP: C23.1, C24.1, U1.49 (VCAP_1), U1.73 (VCAP_2)

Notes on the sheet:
Near VDD/VCC pair
Near VDDA/VCCA pair and Vref
Near VCAP
Near standalone VDD

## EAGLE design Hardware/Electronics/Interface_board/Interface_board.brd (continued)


Board: 2 copper layers, 161.0 x 61.1 mm, 35 parts (0 on the bottom side), 36 nets.

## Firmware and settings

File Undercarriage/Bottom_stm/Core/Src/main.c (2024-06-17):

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
/* Includes ------------------------------------------------------------------*/
#include "main.h"

/* USER CODE BEGIN Includes */
#include <stdio.h>
#include <stdlib.h>
#include <string.h>
/* USER CODE END Includes */

ADC_HandleTypeDef hadc1;
ADC_HandleTypeDef hadc2;
ADC_HandleTypeDef hadc3;
ADC_HandleTypeDef hadc4;
ADC_HandleTypeDef hadc5;

HRTIM_HandleTypeDef hhrtim1;

TIM_HandleTypeDef htim1;
TIM_HandleTypeDef htim2;
TIM_HandleTypeDef htim3;
TIM_HandleTypeDef htim8;
TIM_HandleTypeDef htim16;
TIM_HandleTypeDef htim20;

UART_HandleTypeDef huart4;

void SystemClock_Config(void);
static void MX_GPIO_Init(void);
static void MX_ADC1_Init(void);
static void MX_ADC2_Init(void);
static void MX_ADC3_Init(void);
static void MX_ADC4_Init(void);
static void MX_ADC5_Init(void);
static void MX_HRTIM1_Init(void);
static void MX_TIM1_Init(void);
static void MX_TIM2_Init(void);
static void MX_TIM3_Init(void);
static void MX_TIM8_Init(void);
static void MX_TIM20_Init(void);
static void MX_UART4_Init(void);
static void MX_TIM16_Init(void);
/* USER CODE BEGIN 0 */
#define SENSOR_COUNT 7
#define MOTOR_COUNT 4
#define SEND_BUFFER_SIZE 128
#define READ_BUFFER_SIZE 128
#define MSG_G_SIZE 40
#define MSG_H_SIZE 48
#define TIME_BETWEEN_SEND 6 // 20
#define TIME_BETWEEN_KICK 1000
#define KICK_LENGTH 100

uint16_t lineSensorValue [SENSOR_COUNT]= {0,0,0,0,0,0,0};
uint16_t gateSensorValue = 0; // inverted values from the light gate
int16_t motorValue[MOTOR_COUNT]= {0,0,0,0};
int motorValUpdated = 1;
int16_t dribblerValue = 0;
uint8_t kickerValue = 0;
uint8_t kicked = 0;
uint32_t lastKick = 0;
uint32_t lastMsgRecieved = 0;

uint32_t huart4_TxStart = 0;
uint32_t huart4_TxDuration = 0;
uint32_t huart4_TxInProgress = 0;
uint32_t huart4_TxLastSent = 0;
int huart4_TxErrCnt = 0;

char huart4_RxBuffer[READ_BUFFER_SIZE];
int huart4_RxErrCnt = 0;
int huart4_RxErrCnt2 = 0;
//int huart4_RxErrCnt3 = 0;

uint32_t loop_start = 0;
uint32_t loop_duration = 0;

void my_ADC_Init(ADC_HandleTypeDef *hadc){
	if (HAL_ADC_DeInit(hadc) != HAL_OK)
	{
		Error_Handler();
	}
	//ADC_MultiModeTypeDef multimode = {0};

	hadc->Init.ScanConvMode = ADC_SCAN_DISABLE;
	hadc->Init.EOCSelection = ADC_EOC_SINGLE_CONV;

	hadc->Init.ContinuousConvMode = DISABLE;
	hadc->Init.NbrOfConversion = 1;

	if (HAL_ADC_Init(hadc) != HAL_OK)
	{
		Error_Handler();
	}

	/*multimode.Mode = ADC_MODE_INDEPENDENT;
	if (HAL_ADCEx_MultiModeConfigChannel(hadc, &multimode) != HAL_OK)
	{
		Error_Handler();
	}*/
}

void my_ADC_Start(ADC_HandleTypeDef *hadc, uint32_t channel){
	ADC_ChannelConfTypeDef sConfig = {0};

	sConfig.Channel = channel;
	sConfig.Rank = ADC_REGULAR_RANK_1;
	sConfig.SamplingTime = ADC_SAMPLETIME_2CYCLES_5;
	sConfig.SingleDiff = ADC_SINGLE_ENDED;
	sConfig.OffsetNumber = ADC_OFFSET_NONE;
	sConfig.Offset = 0;
	if (HAL_ADC_ConfigChannel(hadc, &sConfig) != HAL_OK)
	{
		Error_Handler();
	}

	HAL_ADC_Start(hadc);
}

void LineSensorRead(){
	my_ADC_Start(&hadc1, ADC_CHANNEL_5);
	my_ADC_Start(&hadc2, ADC_CHANNEL_3);
	my_ADC_Start(&hadc3, ADC_CHANNEL_12);
	my_ADC_Start(&hadc4, ADC_CHANNEL_5);

	HAL_ADC_PollForConversion(&hadc1, 1000);
	uint16_t s5 = HAL_ADC_GetValue(&hadc1);
	HAL_ADC_Stop(&hadc1);

	HAL_ADC_PollForConversion(&hadc2, 1000);
	uint16_t s0 = HAL_ADC_GetValue(&hadc2);
	HAL_ADC_Stop(&hadc2);

	HAL_ADC_PollForConversion(&hadc3, 1000);
	uint16_t s2 =  HAL_ADC_GetValue(&hadc3);
	HAL_ADC_Stop(&hadc3);

	HAL_ADC_PollForConversion(&hadc4, 1000);
	uint16_t s6 =  HAL_ADC_GetValue(&hadc4);
	HAL_ADC_Stop(&hadc4);

	my_ADC_Start(&hadc2, ADC_CHANNEL_4);
	my_ADC_Start(&hadc3, ADC_CHANNEL_1);

	HAL_ADC_PollForConversion(&hadc2, 1000);
	uint16_t s1 =  HAL_ADC_GetValue(&hadc2);
	HAL_ADC_Stop(&hadc2);

	HAL_ADC_PollForConversion(&hadc3, 1000);
	uint16_t s3 =  HAL_ADC_GetValue(&hadc3);
	HAL_ADC_Stop(&hadc3);

	my_ADC_Start(&hadc3, ADC_CHANNEL_5);

	HAL_ADC_PollForConversion(&hadc3, 1000);
	uint16_t s4 =  HAL_ADC_GetValue(&hadc3);
	HAL_ADC_Stop(&hadc3);

	if (s5 >= lineSensorValue[5]){
		lineSensorValue[5] = s5;
	}
	if (s0 >= lineSensorValue[0]){
		lineSensorValue[0] = s0;
	}
	if (s2 >= lineSensorValue[2]){
		lineSensorValue[2] = s2;
	}
	if (s6 >= lineSensorValue[6]){
		lineSensorValue[6] = s6;
	}
	if (s1 >= lineSensorValue[1]){
		lineSensorValue[1] = s1;
	}
	if (s3 >= lineSensorValue[3]){
		lineSensorValue[3] = s3;
	}
	if (s4 >= lineSensorValue[4]){
		lineSensorValue[4] = s4;
	}
}

void DriveMotorSet(){
	int16_t realMotorValue[MOTOR_COUNT];
	int8_t realMotorPolarity[MOTOR_COUNT];
	int16_t realDribblerValue;
	int8_t realDribblerPolarity;

	/*motorValue[0] = 100;
	motorValue[1] = 100;
	motorValue[2] = 100;
	motorValue[3] = 100;*/
	if (motorValUpdated == 0){
		return;
	}
	for (int i = 0; i < MOTOR_COUNT; i++) {
		if(motorValue[i] == 0){
			realMotorPolarity[i] = -1;
		}else
		if(motorValue[i] > 0){
			realMotorPolarity[i] = 0;
		} else {
			realMotorPolarity[i] = 1;
		}
		realMotorValue[i] = abs(motorValue[i])*3.788 + 757; // 757 - 0.5V, 0rpm; 4545 - 3V 1000rpm
	}
	{
		if(dribblerValue == 0){
			realDribblerPolarity = -1;
		}else
		if(dribblerValue > 0){
			realDribblerPolarity = 0;
		} else {
			realDribblerPolarity = 1;
		}
		realDribblerValue = abs(dribblerValue)*3.788 + 757; // 757 - 0.5V, 0rpm; 4545 - 3V ?rpm
	}

	if(realMotorPolarity[0] == -1){
		HAL_GPIO_WritePin(M1_CWE_GPIO_Port, M1_CWE_Pin, 0);
		HAL_GPIO_WritePin(M1_CCWE_GPIO_Port, M1_CCWE_Pin, 0);

		__HAL_TIM_SET_COMPARE(&htim1, TIM_CHANNEL_1, realMotorValue[0]);
	} else
	if(realMotorPolarity[0] > 0){
		HAL_GPIO_WritePin(M1_CWE_GPIO_Port, M1_CWE_Pin, 1);
		HAL_GPIO_WritePin(M1_CCWE_GPIO_Port, M1_CCWE_Pin, 0);

		__HAL_TIM_SET_COMPARE(&htim1, TIM_CHANNEL_1, realMotorValue[0]);
	} else {
		HAL_GPIO_WritePin(M1_CWE_GPIO_Port, M1_CWE_Pin, 0);
		HAL_GPIO_WritePin(M1_CCWE_GPIO_Port, M1_CCWE_Pin, 1);

		__HAL_TIM_SET_COMPARE(&htim1, TIM_CHANNEL_1, realMotorValue[0]);
	}

	if(realMotorPolarity[2] == -1){
		HAL_GPIO_WritePin(M2_CWE_GPIO_Port, M2_CWE_Pin, 0);
		HAL_GPIO_WritePin(M2_CCWE_GPIO_Port, M2_CCWE_Pin, 0);

		__HAL_TIM_SET_COMPARE(&htim20, TIM_CHANNEL_1, realMotorValue[2]);
	} else
	if(realMotorPolarity[2] > 0){
		HAL_GPIO_WritePin(M2_CWE_GPIO_Port, M2_CWE_Pin, 0);
		HAL_GPIO_WritePin(M2_CCWE_GPIO_Port, M2_CCWE_Pin, 1);

		__HAL_TIM_SET_COMPARE(&htim20, TIM_CHANNEL_1, realMotorValue[2]);
	} else {
		HAL_GPIO_WritePin(M2_CWE_GPIO_Port, M2_CWE_Pin, 1);
		HAL_GPIO_WritePin(M2_CCWE_GPIO_Port, M2_CCWE_Pin, 0);

		__HAL_TIM_SET_COMPARE(&htim20, TIM_CHANNEL_1, realMotorValue[2]);
	}

	if(realMotorPolarity[1] == -1){
		HAL_GPIO_WritePin(M3_CWE_GPIO_Port, M3_CWE_Pin, 0);
		HAL_GPIO_WritePin(M3_CCWE_GPIO_Port, M3_CCWE_Pin, 0);

		__HAL_TIM_SET_COMPARE(&htim8, TIM_CHANNEL_1, realMotorValue[1]);
	} else
	if(realMotorPolarity[1] > 0){
		HAL_GPIO_WritePin(M3_CWE_GPIO_Port, M3_CWE_Pin, 0);
		HAL_GPIO_WritePin(M3_CCWE_GPIO_Port, M3_CCWE_Pin, 1);

		__HAL_TIM_SET_COMPARE(&htim8, TIM_CHANNEL_1, realMotorValue[1]);
	} else {
		HAL_GPIO_WritePin(M3_CWE_GPIO_Port, M3_CWE_Pin, 1);
		HAL_GPIO_WritePin(M3_CCWE_GPIO_Port, M3_CCWE_Pin, 0);

		__HAL_TIM_SET_COMPARE(&htim8, TIM_CHANNEL_1, realMotorValue[1]);
	}

	if(realMotorPolarity[3] == -1){
		HAL_GPIO_WritePin(M4_CWE_GPIO_Port, M4_CWE_Pin, 0);
		HAL_GPIO_WritePin(M4_CCWE_GPIO_Port, M4_CCWE_Pin, 0);

		__HAL_HRTIM_SETCOMPARE(&hhrtim1, HRTIM_TIMERINDEX_TIMER_B, HRTIM_COMPAREUNIT_2, realMotorValue[3]);
		HAL_HRTIM_SoftwareUpdate(&hhrtim1, HRTIM_TIMERUPDATE_B);
	} else
	if(realMotorPolarity[3] > 0){
		HAL_GPIO_WritePin(M4_CWE_GPIO_Port, M4_CWE_Pin, 1);
		HAL_GPIO_WritePin(M4_CCWE_GPIO_Port, M4_CCWE_Pin, 0);

		__HAL_HRTIM_SETCOMPARE(&hhrtim1, HRTIM_TIMERINDEX_TIMER_B, HRTIM_COMPAREUNIT_2, realMotorValue[3]);
		HAL_HRTIM_SoftwareUpdate(&hhrtim1, HRTIM_TIMERUPDATE_B);
	} else {
		HAL_GPIO_WritePin(M4_CWE_GPIO_Port, M4_CWE_Pin, 0);
		HAL_GPIO_WritePin(M4_CCWE_GPIO_Port, M4_CCWE_Pin, 1);

		__HAL_HRTIM_SETCOMPARE(&hhrtim1, HRTIM_TIMERINDEX_TIMER_B, HRTIM_COMPAREUNIT_2, realMotorValue[3]);
		HAL_HRTIM_SoftwareUpdate(&hhrtim1, HRTIM_TIMERUPDATE_B);
	}

	if(realDribblerPolarity == -1){
		HAL_GPIO_WritePin(MD_CWE_GPIO_Port, MD_CWE_Pin, 0);
		HAL_GPIO_WritePin(MD_CCWE_GPIO_Port, MD_CCWE_Pin, 0);

		__HAL_TIM_SET_COMPARE(&htim16, TIM_CHANNEL_1, realDribblerValue);
	} else
	if(realDribblerPolarity > 0){
		HAL_GPIO_WritePin(MD_CWE_GPIO_Port, MD_CWE_Pin, 0);
		HAL_GPIO_WritePin(MD_CCWE_GPIO_Port, MD_CCWE_Pin, 1);

		__HAL_TIM_SET_COMPARE(&htim16, TIM_CHANNEL_1, realDribblerValue);
	} else {
		HAL_GPIO_WritePin(MD_CWE_GPIO_Port, MD_CWE_Pin, 0);
		HAL_GPIO_WritePin(MD_CCWE_GPIO_Port, MD_CCWE_Pin, 1);

		__HAL_TIM_SET_COMPARE(&htim16, TIM_CHANNEL_1, realDribblerValue);
	}

	if((kicked == 1) && (lastKick + KICK_LENGTH <= HAL_GetTick())){
		kicked = 2;
		HAL_GPIO_WritePin(KICK_GPIO_Port, KICK_Pin, 0);
	}
	if((kicked == 2) && (lastKick + TIME_BETWEEN_KICK <= HAL_GetTick())){
		kicked = 0;
	}
	if((kicked == 0) && (kickerValue > 0)){
		HAL_GPIO_WritePin(KICK_GPIO_Port, KICK_Pin, 1);
		lastKick = HAL_GetTick();
		kicked = 1;
	}


	motorValUpdated = 0;
}

void HAL_UART_TxCpltCallback(UART_HandleTypeDef *huart)
{
	//vyhodnotenie dlzky transmitu
	// nastavenie flagu o ukonceni komunikacie
	if(huart == &huart4){
		huart4_TxDuration = HAL_GetTick() - huart4_TxStart;
		huart4_TxInProgress = 0;
		huart4_TxErrCnt++;
	}
}

void HAL_UART_RxCpltCallback(UART_HandleTypeDef *huart)
{
	huart4_RxErrCnt++;
	if(huart == &huart4){
		int j = 0;
		while((huart4_RxBuffer[j] != '{') && (j< MSG_G_SIZE)){
			j++;
		}
		if((j > 0) && (j< MSG_G_SIZE)){
			for (int k = j; k < MSG_G_SIZE; k++) {
				huart4_RxBuffer[k-j] = huart4_RxBuffer[k];
			}
			HAL_UART_Receive_IT(&huart4, (uint8_t *)&huart4_RxBuffer[MSG_G_SIZE-j], j);
			//res7 = HAL_UART_Receive(&huart7, (uint8_t *)huart7_RxBuffer, MSG_H_SIZE, 10);
		} else {
			if(huart4_RxBuffer[0] == '{' && huart4_RxBuffer[2] == 'g' && huart4_RxBuffer[MSG_G_SIZE-2] == '}'){
				huart4_RxErrCnt2++;
				int i = 6;
				while((huart4_RxBuffer[i] != '\"') && (huart4_RxBuffer[i] != '\'') && (i< MSG_G_SIZE)){
					i++;
				}
				if(i<MSG_G_SIZE){
					huart4_RxBuffer[i] = 0;
					int res3, d1, d2, d3, d4, d5, d6;
					res3 = sscanf(&huart4_RxBuffer[6], "%d,%d,%d,%d,%d,%d", &d1, &d2, &d3, &d4, &d5, &d6);
					if(res3 == 6){
						motorValue[0] = d1;
						motorValue[1] = d2;
						motorValue[2] = d3;
						motorValue[3] = d4;
						dribblerValue = d5;
						kickerValue = d6;
						motorValUpdated = 1;
						lastMsgRecieved = HAL_GetTick();
					}
				}
			}
			HAL_UART_Receive_IT(&huart4, (uint8_t *)huart4_RxBuffer, MSG_G_SIZE);
		}
	}
}
/* USER CODE END 0 */

/**
  * @brief  The application entry point.
  * @retval int
  */
int main(void)
{
  /* MCU Configuration--------------------------------------------------------*/

  /* Reset of all peripherals, Initializes the Flash interface and the Systick. */
  HAL_Init();

  /* Configure the system clock */
  SystemClock_Config();

  /* Initialize all configured peripherals */
  MX_GPIO_Init();
  MX_ADC1_Init();
  MX_ADC2_Init();
  MX_ADC3_Init();
  MX_ADC4_Init();
  MX_ADC5_Init();
  MX_HRTIM1_Init();
  MX_TIM1_Init();
  MX_TIM2_Init();
  MX_TIM3_Init();
  MX_TIM8_Init();
  MX_TIM20_Init();
  MX_UART4_Init();
  MX_TIM16_Init();
  /* USER CODE BEGIN 2 */
  my_ADC_Init(&hadc1);
  my_ADC_Init(&hadc2);
  my_ADC_Init(&hadc3);
  my_ADC_Init(&hadc4);

  HAL_TIM_PWM_Start(&htim1, TIM_CHANNEL_1);
  HAL_TIM_PWM_Start(&htim20, TIM_CHANNEL_1);
  HAL_TIM_PWM_Start(&htim8, TIM_CHANNEL_1);
  HAL_HRTIM_SimplePWMStart(&hhrtim1, HRTIM_TIMERINDEX_TIMER_B, HRTIM_OUTPUT_TB2);
  HAL_TIM_PWM_Start(&htim16, TIM_CHANNEL_1);

  for (int i = 0; i < READ_BUFFER_SIZE; ++i) {
	  huart4_RxBuffer[i] = 0;
  }
  HAL_StatusTypeDef res;
  res = HAL_UART_Receive_IT(&huart4, (uint8_t *)huart4_RxBuffer, MSG_G_SIZE);
  if (res != HAL_OK)
  {
	  Error_Handler();
  }
  HAL_GPIO_WritePin(KICK_GPIO_Port, KICK_Pin, 0);
  /* USER CODE END 2 */

  /* Infinite loop */
  /* USER CODE BEGIN WHILE */
  while (1)
  {
    /* USER CODE END WHILE */

    /* USER CODE BEGIN 3 */
	  loop_start = HAL_GetTick();
	  LineSensorRead();
	  DriveMotorSet();

	  //HAL_GPIO_WritePin(GPIO_LED_GPIO_Port, GPIO_LED_Pin, 0);

	  if(HAL_GetTick() - lastMsgRecieved > 1000){
		  motorValue[0] = 0;
		  motorValue[1] = 0;
		  motorValue[2] = 0;
		  motorValue[3] = 0;
		  motorValUpdated = 1;
		  lastMsgRecieved = HAL_GetTick();
	  }

	  if((huart4_TxInProgress == 0) && (HAL_GetTick() >= huart4_TxLastSent + TIME_BETWEEN_SEND)){
		  huart4_TxStart = HAL_GetTick();
		  huart4_TxInProgress = 1;

		  char msg2[SEND_BUFFER_SIZE];
		  		  //HAL_GPIO_WritePin(GPIO_LED_GPIO_Port, GPIO_LED_Pin, 1);
		  sprintf(msg2, "{\"h\":\"%d,%d,%d,%d,%d,%d,%d,%d\"", (int) lineSensorValue[0], (int)lineSensorValue[1], (int)lineSensorValue[2], (int)lineSensorValue[3], (int)lineSensorValue[4], (int)lineSensorValue[5], (int)lineSensorValue[6], (int)gateSensorValue);
		  //sprintf(msg2, "{\"h\":\"%d,%d,%d,%d,%d,%d,%d\"", (int) huart4_RxErrCnt2%10000, (int)huart4_TxErrCnt%10000, (int)lineSensorValue[2], (int)lineSensorValue[3], (int)lineSensorValue[4], (int)lineSensorValue[5], (int)lineSensorValue[6]);
		  uint16_t msg2_len = strlen(msg2);
		  while(msg2_len < MSG_H_SIZE-2){
			  msg2[msg2_len++] = ' ';
		  }
		  msg2[msg2_len++] = '}';
		  msg2[msg2_len++] = '\n';

		  HAL_StatusTypeDef res2;
		  res2 = HAL_UART_Transmit_IT(&huart4, (uint8_t *)msg2, msg2_len);

		  if(res2 == HAL_OK){
			  huart4_TxLastSent = huart4_TxStart;
			  for (int i = 0; i < SENSOR_COUNT; i++) {
				  lineSensorValue[i] = 0;
			  }
		  }else{
			  huart4_TxInProgress = 0;
		  }

	  }
	  HAL_Delay(1);
	  loop_duration = HAL_GetTick() - loop_start;
	  /*HAL_Delay(3000);
	  char huart4_RxBuffer2[READ_BUFFER_SIZE];
	  for (int i = 0; i < READ_BUFFER_SIZE; ++i) {
		  huart4_RxBuffer2[i] = 0;
		}

	  HAL_StatusTypeDef res;
		res = HAL_UART_Receive(&huart4, (uint8_t *)huart4_RxBuffer2, MSG_G_SIZE,3000);
		if (res != HAL_OK)
		{
		  Error_Handler();
		} else {
			huart4_RxErrCnt3++;
		}*/
  }
  /* USER CODE END 3 */
}

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


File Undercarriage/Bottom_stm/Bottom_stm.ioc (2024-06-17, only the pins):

Mcu.UserName=STM32G474RETx
PA0.Signal=ADC1_IN1
PA1.Signal=ADC2_IN2
PA10.GPIO_Label=M4_CCWE
PA10.Signal=GPIO_Output
PA11.Signal=HRTIM1_CHB2
PA12.GPIO_Label=M4_CWE
PA12.Signal=GPIO_Output
PA13.Signal=SYS_JTMS-SWDIO
PA14.Signal=SYS_JTCK-SWCLK
PA15.GPIO_Label=KICK
PA15.Signal=GPIO_Output
PA4.GPIO_Label=GPIO_LED
PA4.Signal=GPIO_Output
PA6.Signal=ADC2_IN3
PA7.Signal=ADC2_IN4
PA8.Signal=ADC5_IN1
PA9.Signal=ADC5_IN2
PB0.Signal=ADC3_IN12
PB1.Signal=ADC3_IN1
PB12.Signal=ADC4_IN3
PB13.Signal=ADC3_IN5
PB14.Signal=ADC1_IN5
PB15.Signal=ADC4_IN5
PB2.GPIO_Label=M2_TIM
PB2.Signal=S_TIM20_CH1
PB4.GPIO_Label=MD_TIM
PB4.Signal=S_TIM16_CH1
PB5.GPIO_Label=MD_CWE
PB5.Signal=GPIO_Output
PB6.GPIO_Label=MD_CCWE
PB6.Signal=GPIO_Output
PC0.GPIO_Label=M1_TIM
PC0.Signal=S_TIM1_CH1
PC1.GPIO_Label=M1_CWE
PC1.Signal=GPIO_Output
PC10.Signal=UART4_TX
PC11.Signal=UART4_RX
PC2.GPIO_Label=M1_CCWE
PC2.Signal=GPIO_Output
PC4.GPIO_Label=M2_CWE
PC4.Signal=GPIO_Output
PC5.GPIO_Label=M2_CCWE
PC5.Signal=GPIO_Output
PC6.Signal=S_TIM8_CH1
PC7.GPIO_Label=M3_CCWE
PC7.Signal=GPIO_Output
PC8.GPIO_Label=M3_CWE
PC8.Signal=GPIO_Output
PF0-OSC_IN.Signal=RCC_OSC_IN
PF1-OSC_OUT.Signal=RCC_OSC_OUT

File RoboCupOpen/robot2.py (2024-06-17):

from soccer_robot.soccer_robot import SoccerRobot

from soccer_robot.logger.logger_module import LoggerModule
from soccer_robot.interface.camera_module.front_camera_module import FrontCameraModule
from soccer_robot.interface.camera_module.mirror_camera_module import MirrorCameraModule
from soccer_robot.interface.undercarriage_module import UndercarriageModule
from soccer_robot.interface.ui_module.ui_module import UIModule
from soccer_robot.interface.bluetooth_module import BluetoothModule

# TEMPORARY SOLUTION, should be handled by soccer_robot class in the future
from soccer_robot.visualization.visualizer_module import VisualizationModule

from soccer_robot.mathf import mathf
from soccer_robot.mathf.vector2 import Vector2
import soccer_robot.constants as con
from soccer_robot.utils.timer import Timer

import math
import os
import sys
import time

# import RPi.GPIO as GPIO

KICKOFF_PUSH_TIME = 0

# import RPi.GPIO as GPIO

class Robot(SoccerRobot):
    def on_start(self) -> None:

        # GPIO.setup(16, GPIO.IN)

        LoggerModule.log_debug("Main Process pid: " + str(os.getpid()))

        self.motor_values = (0, 0, 0, 0)
        UndercarriageModule.set_motor_values(*self.motor_values)

        self.ball_position = [0, 0, 0, 0]
        self.goal_position = [0, 0, 0, 0]

        self.see_ball = False
        self.see_goal = False

        self.camera_module = FrontCameraModule
        self.last_checked_front_timer = Timer()
        self.front_timer = Timer()

        self.ball_angle = 0
        self.ball_dist = 0
        self.goal_center_angle = 0
        self.goal_dist = 0

        self.heading = 0

        self.active_i = []
        self.line = []

        self.lock_motors = True
        self.speed = 0
        self.shooting_speed = 0
        self.rotating_speed = 0

        self.backwards_speed = 0
        self.line_avoid_speed = 0

        self.seen_line = False
        self.anti_line_angle = 0
        self.line_timer = Timer()
        self.line_avoid_timer = con.LINE_AVOID_FAST

        self.last_ball_angle = 0
        self.looking_for_ball_phase = 0
        self.last_seen_ball_timer = Timer()

        self.goalie = False
        self.goalie_change_timer = Timer()

        self.should_defend = False
        self.defend_start_timer = Timer()

        self.start_button_timer = Timer()

        self.line_while_going_for_ball = 0

        self.rotating = False
        self.rotating_timer = Timer()

        self.goalie_status = 1

        self.checking_front_camera = False

    def on_update(self) -> None:
        self.motor_values = (0, 0, 0, 0)

        # Set speeds from calibration
        self.speed = self.get_robot_speed()
        self.shooting_speed = self.get_robot_shooting_speed()
        self.rotating_speed = self.get_robot_rotating_speed()

        self.backwards_speed = self.speed
        self.line_avoid_speed = self.speed


        # Get data from other modules
        self.goal_position = FrontCameraModule.get_goal_position()
        self.see_goal = self.goal_position[:2] != [-1, -1]

        max_angle = FrontCameraModule.camera.center_fov / 2


        if self.camera_module == FrontCameraModule and not self.see_ball and not self.checking_front_camera:
            self.camera_module = MirrorCameraModule

        elif self.camera_module == MirrorCameraModule:
            if self.see_ball:
                in_front = self.ball_angle < max_angle or self.ball_angle > (360-max_angle)
                self.camera_module = FrontCameraModule if in_front else MirrorCameraModule
            elif self.last_checked_front_timer.get() > con.FRONT_CHECK_TIME:
                self.camera_module = FrontCameraModule
                self.front_timer.reset()
                self.last_checked_front_timer.reset()
                self.checking_front_camera = True

        if self.camera_module == FrontCameraModule and self.front_timer.get() > con.FRONT_STAY_TIME:
            self.last_checked_front_timer.reset()
            self.front_timer.reset()
            self.checking_front_camera = False

        FrontCameraModule.set_enable_ball(self.camera_module == FrontCameraModule)
        MirrorCameraModule.set_enable_ball(self.camera_module == MirrorCameraModule)
        # MirrorCameraModule.set_enable_goal(True)


        
        self.ball_position = self.camera_module.get_ball_position()
        self.see_ball = self.ball_position[:2] != [-1, -1]
        self.ball_angle, self.ball_dist = self.camera_module.get_angle_dist(self.ball_position)

        # LoggerModule.log_debug(f"ball_angle: {self.ball_angle}, ball_dist: {self.ball_dist}")

        #LoggerModule.log_info(f"angle: {self.ball_angle:2f}, dist {self.ball_dist:2f}, Front enable_ball: {FrontCameraModule.get_enable_ball()}, Mirror enable_ball: {MirrorCameraModule.get_enable_ball()}")

        #LoggerModule.log_debug(f"ball_pos: {self.ball_position}")

        self.heading = UndercarriageModule.get_heading()
        sensor_values = UndercarriageModule.get_color_sensor_values()
        self.lock_motors = UndercarriageModule.get_button_one_status()

        #Log lock_motors

        self.active_i = []
        for i, v in enumerate(sensor_values):
            if v > self.get_line_sensors_threshold():
                self.active_i.append(i)
        self.line = mathf.get_line_pos(self.active_i)


        goal_right_corner_angle = FrontCameraModule.get_angle_dist(
            [self.goal_position[0] + self.goal_position[2] / 2] + self.goal_position[1:],
            con.GOAL_REAL_SIZE, 1
        )[0]
        self.goal_center_angle, self.goal_dist = FrontCameraModule.get_angle_dist(self.goal_position, con.GOAL_REAL_SIZE, 1)
        goal_left_corner_angle = FrontCameraModule.get_angle_dist(
            [self.goal_position[0] - self.goal_position[2] / 2] + self.goal_position[1:],
            con.GOAL_REAL_SIZE, 1
        )[0]
        goal_width_angle = mathf.normalize_angle(goal_right_corner_angle - goal_left_corner_angle)

        if (self.see_ball):
            self.last_seen_ball_timer.reset()
        

        # Decide a goalie
        """
        if BluetoothModule.is_connected() and not BluetoothModule.is_locked():
            if con.ROBOT_INDEX == con.GOALIE_MASTER_INDEX:
                is_time = self.goalie_change_timer.get() >= con.GOALIE_CHANGE_TIME
                if is_time:
                    self.goalie_change_timer.reset()
                    both_see = self.see_ball and BluetoothModule.see_ball()
                    other_is_near = both_see and BluetoothModule.get_ball_angle_dist()[1] <= self.ball_dist
                    self.goalie = BluetoothModule.see_ball() and (not self.see_ball or other_is_near)
            else:
                self.goalie = not BluetoothModule.is_goalie()
        else:
            self.goalie = False
        """

        self.goalie = False

        in_front = self.ball_angle < max_angle or self.ball_angle > (360-max_angle)
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

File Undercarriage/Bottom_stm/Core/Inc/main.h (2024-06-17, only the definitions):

#define M1_TIM_Pin GPIO_PIN_0
#define M1_TIM_GPIO_Port GPIOC
#define M1_CWE_Pin GPIO_PIN_1
#define M1_CWE_GPIO_Port GPIOC
#define M1_CCWE_Pin GPIO_PIN_2
#define M1_CCWE_GPIO_Port GPIOC
#define GPIO_LED_Pin GPIO_PIN_4
#define GPIO_LED_GPIO_Port GPIOA
#define M2_CWE_Pin GPIO_PIN_4
#define M2_CWE_GPIO_Port GPIOC
#define M2_CCWE_Pin GPIO_PIN_5
#define M2_CCWE_GPIO_Port GPIOC
#define M2_TIM_Pin GPIO_PIN_2
#define M2_TIM_GPIO_Port GPIOB
#define M3_CCWE_Pin GPIO_PIN_7
#define M3_CCWE_GPIO_Port GPIOC
#define M3_CWE_Pin GPIO_PIN_8
#define M3_CWE_GPIO_Port GPIOC
#define M4_CCWE_Pin GPIO_PIN_10
#define M4_CCWE_GPIO_Port GPIOA
#define M4_CWE_Pin GPIO_PIN_12
#define M4_CWE_GPIO_Port GPIOA
#define KICK_Pin GPIO_PIN_15
#define KICK_GPIO_Port GPIOA
#define MD_TIM_Pin GPIO_PIN_4
#define MD_TIM_GPIO_Port GPIOB
#define MD_CWE_Pin GPIO_PIN_5
#define MD_CWE_GPIO_Port GPIOB
#define MD_CCWE_Pin GPIO_PIN_6
#define MD_CCWE_GPIO_Port GPIOB

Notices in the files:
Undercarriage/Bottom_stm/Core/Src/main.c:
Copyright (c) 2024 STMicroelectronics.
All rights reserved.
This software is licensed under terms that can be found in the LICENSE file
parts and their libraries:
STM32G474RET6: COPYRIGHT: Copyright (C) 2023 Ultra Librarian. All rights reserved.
